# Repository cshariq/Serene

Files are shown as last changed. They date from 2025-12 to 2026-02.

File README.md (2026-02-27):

# SERENE

Can't hear your friend talking on the highway? Do you need to blast your music just to hear it well? Well, you're in luck, because **Serene** is a portable noise-cancelling device that can remove all of that noise!

Just stick it to the roof of your car, and Serene will capture the road noise and output sounds waves that cancel them out, so that you can enjoy a peaceful car ride. 

Serene is a small, portable device that connects directly to your phone and car speaker. It sticks seamlessly to the walls of your car, and using ANC algorithms, it minimizes the external noise that it picks up inside the car.  

---

## Inspiration 

During family road trips, I sat in the backseat as a child, and if I didn't yell, my parents in the front couldn't hear me. This was so annoying, as a long highway drive almost always came with losing my voice. 

With my dad's hearing getting worse, I figured that we needed a way to drown out the road noise. I was desparate for a solution, so taking inspiration from noise-cancelling technology in headphones, I thought: "What if we did the same thing in cars?". 

While a few very luxury cars offer ANC, I wanted to make ANC more accessible to all people, because everyone deserves sereneness!

---

## How to use Serene

1. Click the power ON button at the top of the casing. 
2. Download the Serene app and pair your mobile device through Bluetooth / AUX / USB. 
3. Proceed with the calibration process.
4. Stick the Serene device anywhere in your car.
5. Turn the car on and start your peaceful drive.

---

## 3D Model: [OnShape Link](https://cad.onshape.com/documents/61c8b07b134ed299bc7b3a3e/w/ec2ebddc7aaece6417831267/e/c16017c5fc26cf24515a7a41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)

### PCB:



### Casing:



---

## PCB
### Main PCB


### Button PCB


---

## Wiring Diagram
### Main PCB


### Button PCB



---

## BOM
| Quantity | Part Name | Compoenent | Price(1 Quantity) | Total Price for all quantiy | Link | Status |
|---|---|---|---|---|---|---|
| 1 | WQFN-HR18__RYK_TEX | Power Chip | $2.48 | $2.48 | https://jlcpcb.com/partdetail/TexasInstruments-BQ25620RYKR/C6164243 | In Stock  |
| 2 | CONN_X.FL-R-SMT-180_HIR | Coaxial Connector for bluetooth and UWB antennas | $0.27 | $0.53 | https://jlcpcb.com/partdetail/HRS_Hirose-X_FL_R_SMT_1_80/C434819 | In Stock  |
| 17 | C_0402_1005Metric | Capacitor, 0.1uF | $0.00 | $0.03 | https://jlcpcb.com/partdetail/MurataElectronics-GRM155R71C104KA88D/C71629 | In Stock  |
| 1 | C_0402_1005Metric | Capacitor, 47nF | $0.00 | $0.00 | https://jlcpcb.com/partdetail/MurataElectronics-GRM155R71E473KA88D/C77017 | In Stock  |
| 1 | Spark_SR1120_QFN32 | UWB Chip, used for audio transmission | $16.54 | $16.54 | https://jlcpcb.com/partdetail/SPARKMicrosystems-SR1120AA_4Q32TR/C47090725 | Pre-Order |
| 1 | SOT-23-5 | 1.8V Power Regulator | $0.11 | $0.11 | https://jlcpcb.com/partdetail/DiodesIncorporated-AP2112K_18TRG1/C176944 | In Stock  |
| 2 | Infineon_PG-LLGA-5-2 | Mics | $10.28 | $20.56 | https://www.aliexpress.com/item/1005009306016183.html?gatewayAdapt=4itemAdapt | In Stock  |
| 1 | USB_C_Receptacle_GCT_USB4085 | USB C Port (USB 2.0) | $1.19 | $1.19 | https://jlcpcb.com/partdetail/8061907-USB4085_GFA/C7095263 | In Stock  |
| 1 | Jack_3.5mm_CUI_SJ2-3593D-SMT_Horizontal | Headphone Jack | $11.30 | $11.30 | https://jlcpcb.com/partdetail/CUI-SJ2_3593D_SMTTR/C4991621 | In Stock  |
| 4 | R_0402_1005Metric | Resistor, 100kΩ | $0.01 | $0.04 | https://jlcpcb.com/partdetail/YAGEO-RC0402FR07100KL/C60491 | In Stock  |
| 1 | STM32H743ZIT6 | Microcontroller, STM32H743ZIT6 | $8.19 | $8.19 | https://jlcpcb.com/partdetail/STMicroelectronics-STM32H743ZIT6/C114408 | In Stock  |
| 7 | C_0402_1005Metric | Capacitor, 10uF | $0.01 | $0.07 | https://jlcpcb.com/partdetail/MurataElectronics-GRM155R60J106ME44D/C76991 | In Stock  |
| 1 | C_0402_1005Metric | Capacitor, 4.7µF | $0.01 | $0.01 | https://jlcpcb.com/partdetail/313626-GRM155R61A475MEAAD/C335105 | In Stock  |
| 1 | ADXL382_Ultralib | Vibration Sensor, used for predicting sound | $28.05 | $28.05 | https://jlcpcb.com/partdetail/AnalogDevices-ADXL382_1BCCZRL7/C41718413 | In Stock  |
| 1 | L_0603_1608Metric | Inductor, 180nH | $0.09 | $0.09 | https://jlcpcb.com/partdetail/MurataElectronics-LQW18ANR18G80D/C162650 | In Stock  |
| 1 | Crystal_SMD_3225-4Pin_3.2x2.5mm | Crystal, 32.768 kHz | $0.49 | $0.49 | https://jlcpcb.com/partdetail/AbraconLLC-ABS07_32_768KHZT/C130253 | In Stock  |
| 5 | C_0402_1005Metric | Capacitor, 1uF | $0.01 | $0.05 | https://jlcpcb.com/partdetail/MurataElectronics-GRM155R61A105KE15D/C76999 | In Stock  |
| 6 | C_0402_1005Metric | Capacitor, 10pF | $0.01 | $0.06 | https://jlcpcb.com/partdetail/MurataElectronics-GRM1555C1H100JA01D/C76946 | In Stock  |
| 1 | ADAU1787_Ultralib | DSP(Digital Signal Processor) used for processing sound | $19.07 | $19.07 | https://jlcpcb.com/partdetail/AnalogDevices-ADAU1787BCBZRL7/C3226201 | In Stock  |
| 1 | SOT-223-3_TabPin2 | 3.3V Power Regulator | $0.29 | $0.29 | https://jlcpcb.com/partdetail/DiodesIncorporated-AP7361C_33E13/C500795 | In Stock  |
| 2 | R_0402_1005Metric | Resistor, 5.1k | $0.01 | $0.02 | https://jlcpcb.com/partdetail/YAGEO-RC0402FR075K1L/C105872 | In Stock  |
| 1 | L_0603_1608Metric | Inductor, 1.5uH | $0.10 | $0.10 | https://jlcpcb.com/partdetail/MurataElectronics-DFE252012F_1R5MP2/C909806 | In Stock  |
| 1 | BGM220S_SIL | Bluetooth Chip | $13.84 | $13.84 | https://jlcpcb.com/partdetail/1603489-BGM220SC12WGA2R/C1512693 | Pre-Order |
| 1 | Crystal_SMD_3225-4Pin_3.2x2.5mm | Crystal | $0.08 | $0.08 | https://jlcpcb.com/partdetail/YXC_CrystalOscillators-X322525MQB4SI/C70585 | In Stock  |
| 1 | Balun_Johanson_1.6x0.8mm | Transformer | $8.97 | $8.97 | https://jlcpcb.com/partdetail/YXC_CrystalOscillators-X322525MQB4SI/C70585 | In Stock  |
| 2 | R_0402_1005Metric | Resistor, 2.2kΩ | $0.01 | $0.02 | https://jlcpcb.com/partdetail/YAGEO-RC0402FR072K2L/C114762 | In Stock  |
| 1 | R_0402_1005Metric | Resistor, 170Ω | $0.01 | $0.01 | https://jlcpcb.com/partdetail/YAGEO-RC0402FR07180RL/C138045 | In Stock  |
| 5 | R_0402_1005Metric | Resistor, 10kΩ | $0.01 | $0.05 | https://jlcpcb.com/partdetail/YAGEO-RC0402FR0710KL/C60490 | In Stock  |
| 2 | C_0402_1005Metric | Capacitor, 2.2uF | $0.01 | $0.02 | https://jlcpcb.com/partdetail/MurataElectronics-GRM155R61A225KE95D/C77002 | In Stock  |
| 1 | SOT-23-6 | ESD protection diode, used for headphone jack | $0.13 | $0.13 | https://jlcpcb.com/partdetail/STMicroelectronics-USBLC62SC6/C7519 | In Stock  |
| 2 | CONN_503480-0540_MOL | Molex connector used for linking button PCB with main PCB | $0.83 | $1.66 | https://jlcpcb.com/partdetail/MOLEX-5034800540/C5527934 | In Stock  |
| 3 | LED_SK6805_PLCC4_2.4x2.7mm_P1.3mm | LEDS on the Button PCB | $3.95 | $11.86 | https://www.adafruit.com/product/4492 | In Stock  |
| 1 | SW_Push_1P1T_NO_CK_KMR2 | Button on the Button PCB | $0.61 | $0.61 | https://jlcpcb.com/partdetail/CK-KMR221GLFS/C72443 | In Stock  |
| 1 | Vapcell N40 | Battery | $20.00 | $20.00 | https://www.vapcelltech.com/h-pd-193.html | In Stock  |
| 1 | N/A | Nickel Strips used for connecting the + and - of the battery  | $6.45 | $6.45 | https://www.amazon.ca/Nickel-Plated-Connection-Refined-Welding/dp/B0CPFL5ZWM/ | In Stock  |
| 1 | N/A | Pair of Pogo Pins | $6.06 | $6.06 | https://www.amazon.ca/Connector-Positions-Pogopin-Contact-3PIN/dp/B0BXDFJVVZ?th=1 | In Stock  |
| 1 | N/A | uxcell 45mm x 0.5mm 6 Pin FPC/FFC Flat Ribbon Cable Connector | $9.99 | $9.99 | https://www.amazon.ca/gp/product/B00H8PCW06 | |
| 1 | N/A | N/A | $53.85 | $53.85 | | |
| 1 | N/A | N/A | $7.20 | $7.20 | | |

| Subtotal | Source | Notes |
|---|---|---|
| $228.21 | JLCPCB Parts | 2x (JLCPCB requires 2 of each part) |
| $61.05 | JLCPCB PCB | 0.15mm via and epoxy filled & capped selectedas it is required by the ADAU1787 Chip. Lead free coating also selected for safety and its only a dollar extra. 6 Layer manufacturing is selected because it is cheaper than 2/4 layer manufacturing due to a coupon. Although other options were explored, most DSPs(Digital Singal Processors) which is required for fast processing of audio(required for ANC) are WLCSP chips requiring 0.15mm vias which are epoxy filled & capped. Other solutions are too slow for this application.|
| $22.50 | Amazon | |
| $20.56 | AliExpress | |
| $11.86 | Adafruit | For the LEDs |
| $250.08 | All | Not accounting for 2x JLCPCB Parts |
| $364.18 | All | 2x (JLCPCB required 2 of each part) |

| Grand Total | Price | Notes |
|---|---|---|
| JLCParts Grand Total | $238.13 | 2x (JLCPCB required 2 of each part) |
| JLCPCB Grand Total | $72.25 | JLCPCB Advanced is cheaper due to coupons |
| Amazon Subtotal | $16.28 | 22.5 CAD --> 16.28 USD |
| Adafruit Grand Total | $23.08 | |
| AliExpress Grand Total | $20.70 | 28.07 CAD --> 20.70 USD |
| Vapcell Grand Total | $22.99 | |
| Grand Total | $393.43 | |

### Screenshots of total with shipping and taxes.

Amazon:



JLCPCB Parts:



JLCPCB PCB (6 layer manufacturing for Main PCB, less expensive):



JLCPCB PCB (4 layer manufacturing for Main PCB, more expensive and thus **not used**)



Button PCB:



AliExpress:



Vapcell:



Adafruit:



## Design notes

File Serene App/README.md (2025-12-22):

# serene

A new Flutter project.

## Getting Started

This project is a starting point for a Flutter application.

A few resources to get you started if this is your first Flutter project:

- [Lab: Write your first Flutter app](https://docs.flutter.dev/get-started/codelab)
- [Cookbook: Useful Flutter samples](https://docs.flutter.dev/cookbook)

For help getting started with Flutter development, view the
[online documentation](https://docs.flutter.dev/), which offers tutorials,
samples, guidance on mobile development, and a full API reference.

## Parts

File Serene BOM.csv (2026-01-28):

Quantity | Reference | Footprint Name | Part Name | Compoenent | Manufcaturer Part # | Price(1 Quantity) | Total Price for all quantiy | Source | Link | Status | Digikey Part # | Mouser Part #
1 | U6 | BQ25620RYKR | WQFN-HR18__RYK_TEX | Power Chip | BQ25620RYKR | $2.48 | $2.48 | JLCPCB | https://jlcpcb.com/partdetail/TexasInstruments-BQ25620RYKR/C6164243 | In Stock | 296-BQ25620RYKRCT-ND - Cut Tape (CT) | 595-BQ25620RYKR
2 | J1,J6 | Conn_Coaxial | CONN_X.FL-R-SMT-180_HIR | Coaxial Connector for bluetooth and UWB antennas | X.FL-R-SMT-1(80) | $0.27 | $0.53 | JLCPCB | https://jlcpcb.com/partdetail/HRS_Hirose-X_FL_R_SMT_1_80/C434819 | In Stock | 26-X.FL-R-SMT-1(80)CT-ND - Cut Tape (CT) | 798-X.FL-R-SMT-1(80)
17 | C10,C18,C31,C17,C20,C8,C11,C4,C28,C13,C27,C14,C9,C15,C12,C19,C16 | 0.1uF | C_0402_1005Metric | Capacitor, 0.1uF | GRM155R71C104KA88D | $0.00 | $0.03 | JLCPCB | https://jlcpcb.com/partdetail/MurataElectronics-GRM155R71C104KA88D/C71629 | In Stock | 399-C0603C104K5RACTUCT-ND - Cut Tape (CT) | 963-MBASE105SB7104KF
1 | C37 | 47nF | C_0402_1005Metric | Capacitor, 47nF | GRM155R71E473KA88D | $0.00 | $0.00 | JLCPCB | https://jlcpcb.com/partdetail/MurataElectronics-GRM155R71E473KA88D/C77017 | In Stock | 490-3254-1-ND - Cut Tape (CT) | 81-GRM155R71E473KA88
1 | U9 | ~ | Spark_SR1120_QFN32 | UWB Chip, used for audio transmission | SR1120AA-4Q32-TR | $16.54 | $16.54 | JLCPCB | https://jlcpcb.com/partdetail/SPARKMicrosystems-SR1120AA_4Q32TR/C47090725 | Pre-Order | 3918-SR1120AA-4Q32-TRCT-ND - Cut Tape (CT) | Not avaliable yet, new product
1 | U2 | AP2112K-1.8 | SOT-23-5 | 1.8V Power Regulator | AP2112K-1.8TRG1 | $0.11 | $0.11 | JLCPCB | https://jlcpcb.com/partdetail/DiodesIncorporated-AP2112K_18TRG1/C176944 | In Stock | AP2112K-1.8TRG1DICT-ND - Cut Tape (CT) | 621-AP2112K-1.8TRG1
2 | MK2,MK1 | IM73A135V01 | Infineon_PG-LLGA-5-2 | Mics | IM73A135V01XTSA1 | $10.28 | $20.56 | AliExpress | https://www.aliexpress.com/i/1005008454918413.html | In Stock | 448-IM73A135V01XTSA1CT-ND - Cut Tape (CT) | 726-IM73A135V01XTSA1
1 | J5 | USB_C_Receptacle_USB2.0_14P | USB_C_Receptacle_GCT_USB4085 | USB C Port (USB 2.0) | USB4085-GF-A | $1.19 | $1.19 | JLCPCB | https://jlcpcb.com/partdetail/8061907-USB4085_GFA/C7095263 | In Stock | 2073-USB4085-GF-ACT-ND - Cut Tape (CT) | 640-USB4085-GF-A
1 | J4 | AudioJack3_Switch | Jack_3.5mm_CUI_SJ2-3593D-SMT_Horizontal | Headphone Jack | SJ2-3593D-SMT-TR | $11.30 | $11.30 | JLCPCB | https://jlcpcb.com/partdetail/CUI-SJ2_3593D_SMTTR/C4991621 | In Stock | CP-SJ2-3593D-SMT-CT-ND | 490-SJ2-3593D-SMT-TR
4 | R12,R16,R10,R9 | 100k½ | R_0402_1005Metric | Resistor, 100k½ | RC0402FR-07100KL | $0.01 | $0.04 | JLCPCB | https://jlcpcb.com/partdetail/YAGEO-RC0402FR07100KL/C60491 | In Stock | 311-100KLRCT-ND - Cut Tape (CT) | 603-RC0402FR-07100KL
1 | U3 | STM32H753ZITx | STM32H743ZIT6 | Microcontroller, STM32H743ZIT6 | STM32H743ZIT6 | $8.19 | $8.19 | JLCPCB | https://jlcpcb.com/partdetail/STMicroelectronics-STM32H743ZIT6/C114408 | In Stock | 497-17721-ND | 511-STM32H753ZIT6
7 | C1,C40,C39,C7,C2,C36,C38 | 10uF | C_0402_1005Metric | Capacitor, 10uF | Murata GRM155R60J106ME44D | $0.01 | $0.07 | JLCPCB | https://jlcpcb.com/partdetail/MurataElectronics-GRM155R60J106ME44D/C76991 | In Stock
1 | C35 | 4.7µF | C_0402_1005Metric | Capacitor, 4.7µF | Murata GRM155R61A475MEAAD | $0.01 | $0.01 | JLCPCB | https://jlcpcb.com/partdetail/313626-GRM155R61A475MEAAD/C335105 | In Stock | 490-14306-1-ND - Cut Tape (CT) | 81-GRM155R61A475MEAD
1 | U4 | ADXL382-1BCCZ-RL | ADXL382_Ultralib | Vibration Sensor, used for predicting sound | ADXL382-1BCCZ-RL7 | $28.05 | $28.05 | JLCPCB | https://jlcpcb.com/partdetail/AnalogDevices-ADXL382_1BCCZRL7/C41718413 | In Stock | 505-ADXL382-1BCCZ-RL7CT-ND - Cut Tape (CT) | 584-ADXL382-1BCCZRL7
1 | L1 | 180nH | L_0603_1608Metric | Inductor, 180nH | Murata LQW18ANR18G80D | $0.09 | $0.09 | JLCPCB | https://jlcpcb.com/partdetail/MurataElectronics-LQW18ANR18G80D/C162650 | In Stock | 490-LQW18ANR18G80DCT-ND - Cut Tape (CT) | 81-LQW18ANR18G80D
1 | Y2 | 32.768 kHz | Crystal_SMD_3225-4Pin_3.2x2.5mm | Crystal, 32.768 kHz | ABS07-32.768KHZ-T | $0.49 | $0.49 | JLCPCB | https://jlcpcb.com/partdetail/AbraconLLC-ABS07_32_768KHZT/C130253 | In Stock | 644-STDMUA8-32.768KCT-ND - Cut Tape (CT) | 344-NX3215SA32768K8
5 | C32,C23,C29,C30,C26 | 1uF | C_0402_1005Metric | Capacitor, 1uF | GRM155R61A105KE15D | $0.01 | $0.05 | JLCPCB | https://jlcpcb.com/partdetail/MurataElectronics-GRM155R61A105KE15D/C76999 | In Stock
6 | C33,C25,C34,C3,C6,C24 | 10pF | C_0402_1005Metric | Capacitor, 10pF | GRM1555C1H100JA01D | $0.01 | $0.06 | JLCPCB | https://jlcpcb.com/partdetail/MurataElectronics-GRM1555C1H100JA01D/C76946 | In Stock | 490-5921-1-ND - Cut Tape (CT) | 81-GRM1555C1H100JA1D
1 | U5 | ADAU1787BCBZRL | ADAU1787_Ultralib | DSP(Digital Signal Processor) used for processing sound | ADAU1787BCBZRL | $19.07 | $19.07 | JLCPCB | https://jlcpcb.com/partdetail/AnalogDevices-ADAU1787BCBZRL7/C3226201 | In Stock | 505-ADAU1787BCBZRLCT-ND - Cut Tape (CT) | 584-ADAU1787BCBZRL
1 | U1 | AP7361C-33E | SOT-223-3_TabPin2 | 3.3V Power Regulator | AP7361C-33E-13 | $0.29 | $0.29 | JLCPCB | https://jlcpcb.com/partdetail/DiodesIncorporated-AP7361C_33E13/C500795 | In Stock | AP7361C-33E-13DICT-ND - Cut Tape (CT) | 621-AP7361C-33E-13
2 | R2,R1 | 5.1k | R_0402_1005Metric | Resistor, 5.1k | RC0402FR-075K1L | $0.01 | $0.02 | JLCPCB | https://jlcpcb.com/partdetail/YAGEO-RC0402FR075K1L/C105872 | In Stock | 311-5.10KLRCT-ND - Cut Tape (CT) | 603-RC0402FR-075K1L
1 | L2 | 1.5uH | L_0603_1608Metric | Inductor, 1.5uH | Murata DFE252012F-1R5M=P2 | $0.10 | $0.10 | JLCPCB | https://jlcpcb.com/partdetail/MurataElectronics-DFE252012F_1R5MP2/C909806 | In Stock | 490-13054-1-ND - Cut Tape (CT) | 81-DFE252012F-1R5MP2
1 | U7 | BGM220SC12WGA2R | BGM220S_SIL | Bluetooth Chip | BGM220SC12WGA2R | $13.84 | $13.84 | JLCPCB | https://jlcpcb.com/partdetail/1603489-BGM220SC12WGA2R/C1512693 | Pre-Order | 336-BGM220SC12WGA2RCT-ND - Cut Tape (CT) | 634-BGM220SC12WGA2R
1 | Y1 | Crystal_GND24 | Crystal_SMD_3225-4Pin_3.2x2.5mm | Crystal | X322525MQB4SI | $0.08 | $0.08 | JLCPCB | https://jlcpcb.com/partdetail/YXC_CrystalOscillators-X322525MQB4SI/C70585 | In Stock
1 | T1 | Transformer_1P_1S | Balun_Johanson_1.6x0.8mm | Transformer | Johanson 6750BL14A0100001T | $8.97 | $8.97 | JLCPCB | https://jlcpcb.com/partdetail/YXC_CrystalOscillators-X322525MQB4SI/C70585 | In Stock
2 | R4,R5 | 2.2k½ | R_0402_1005Metric | Resistor, 2.2k½ | RC0402FR-072K2L | $0.01 | $0.02 | JLCPCB | https://jlcpcb.com/partdetail/YAGEO-RC0402FR072K2L/C114762 | In Stock | 311-2.20KLRCT-ND - Cut Tape (CT) | 603-RC0402FR-072K2L
1 | R6 | 170½ | R_0402_1005Metric | Resistor, 170½ | RC0402FR-07170RL | $0.01 | $0.01 | JLCPCB | https://jlcpcb.com/partdetail/YAGEO-RC0402FR07180RL/C138045 | In Stock
5 | R8,R15,R11,R7, R3 | 10k½ | R_0402_1005Metric | Resistor, 10k½ | RC0402FR-0710KL | $0.01 | $0.05 | JLCPCB | https://jlcpcb.com/partdetail/YAGEO-RC0402FR0710KL/C60490 | In Stock | 311-10.0KLRCT-ND - Cut Tape (CT) | 603-RC0402FR-0710KL
2 | C21,C22 | 2.2uF | C_0402_1005Metric | Capacitor, 2.2uF | GRM155R61A225KE95D | $0.01 | $0.02 | JLCPCB | https://jlcpcb.com/partdetail/MurataElectronics-GRM155R61A225KE95D/C77002 | In Stock
1 | U8 | USBLC6-2SC6 | SOT-23-6 | ESD protection diode, used for headphone jack | USBLC6-2SC6 | $0.13 | $0.13 | JLCPCB | https://jlcpcb.com/partdetail/STMicroelectronics-USBLC62SC6/C7519 | In Stock | 497-5235-1-ND - Cut Tape (CT) | 511-USBLC6-2SC6
2 | J2 | Conn_01x06_Socket | CONN_503480-0540_MOL | Molex connector used for linking button PCB with main PCB | 5034800540 | $0.83 | $1.66 | JLCPCB | https://jlcpcb.com/partdetail/MOLEX-5034800540/C5527934 | In Stock | 900-5034800540CT-ND - Cut Tape (CT) | 538-503480-0540
3 | D18,D9,D2,D7,D16,D12,D5,D13,D20,D15,D21,D8,D14,D1,D3,D11,D4,D10,D6,D17,D19 | SK6805 | LED_SK6805_PLCC4_2.4x2.7mm_P1.3mm | LEDS on the Button PCB | SK6805-E-J | $3.95 | $11.86 | Adafruit (cheaper than digikey) | https://www.adafruit.com/product/4492 | In Stock
1 | SW1 | SW_Push | SW_Push_1P1T_NO_CK_KMR2 | Button on the Button PCB | KMR221GLFS | $0.61 | $0.61 | JLCPCB | https://jlcpcb.com/partdetail/CK-KMR221GLFS/C72443 | In Stock
1 | Battery | N/A | Vapcell N40 | Battery | Vapcell N40 | $20.00 | $20.00 | VAPCELL | https://www.vapcelltech.com/h-pd-193.html | In Stock
1 | Nickel Strips | N/A | N/A | Nickel Strips used for connecting the + and - of the battery | N/A | $6.45 | $6.45 | Amazon | https://www.amazon.ca/Nickel-Plated-Connection-Refined-Welding/dp/B0CPFL5ZWM/ | In Stock
1 | Pogo Pins | N/A | N/A | Pair of Pogo Pins | N/A | $6.06 | $6.06 | Amazon | https://www.amazon.ca/Connector-Positions-Pogopin-Contact-3PIN/dp/B0BXDFJVVZ?th=1 | In Stock
1 | FPC/FFC Flat Ribbon Cable | N/A | N/A | uxcell 45mm x 0.5mm 6 Pin FPC/FFC Flat Ribbon Cable Connector | N/A | $9.99 | $9.99 | Amazon | https://www.amazon.ca/gp/product/B00H8PCW06
1 | Main PCB | N/A | N/A | N/A | N/A | $53.85 | $53.85 | JLCPCB PCB
1 | Button PCB | N/A | N/A | N/A | N/A | $7.20 | $7.20 | JLCPCB PCB
 |  |  |  |  |  | Subtotal | Source | Notes
 |  |  |  |  |  | $228.21 | JLCPCB Parts | 2x (JLCPCB required 2 of each part)
 |  |  |  |  |  | $61.05 | JLCPCB PCB | 0.15mm via and expoxy filled & capped selectedas it is required by the ADAU1787 Chip. Lead free coating also selecte, because I don't lead and its only a dollar extra.
 |  |  |  |  |  | $22.50 | Amazon | For the pogo pin + molex ribon cable
 |  |  |  |  |  | $22.50 | Amazon
 |  |  |  |  |  | $20.56 | AliExpress
 |  |  |  |  |  | $11.86 | Adafruit | For the LEDs
 |  |  |  |  |  | $250.08 | All | Not accounting for 2x JLCPCB Parts
 |  |  |  |  |  | $364.18 | All | 2x (JLCPCB required 2 of each part)
 |  |  |  |  |  | JLCParts Grand Total | $238.13 | 2x (JLCPCB required 2 of each part)
 |  |  |  |  |  | JLCPCB Grand Total | $72.25 | JLCPCB Advanced is cheaper due to coupons
 |  |  |  |  |  | Amazon Subtotal | $16.28 | 22.5 CAD --> 16.28 USD
 |  |  |  |  |  | Adafruit Grand Total | $23.08
 |  |  |  |  |  | AliExpress Grand Total | $20.70 | 28.07 CAD --> 20.70 USD
 |  |  |  |  |  | Vapcell Grand Total | $22.99
 |  |  |  |  |  | Grand Total | $393.43

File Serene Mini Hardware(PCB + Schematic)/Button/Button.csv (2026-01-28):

Id | Designator | Footprint | Quantity | Designation | Supplier and ref
1 | J2 | CONN_503480-0540_MOL | 1 | Conn_01x06_Socket
2 | D18,D9,D2,D7,D16,D12,D5,D13,D20,D15,D21,D8,D14,D1,D3,D11,D4,D10,D6,D17,D19 | LED_SK6805_PLCC4_2.4x2.7mm_P1.3mm | 21 | SK6805
3 | SW1 | SW_Push_1P1T_NO_CK_KMR2 | 1 | SW_Push

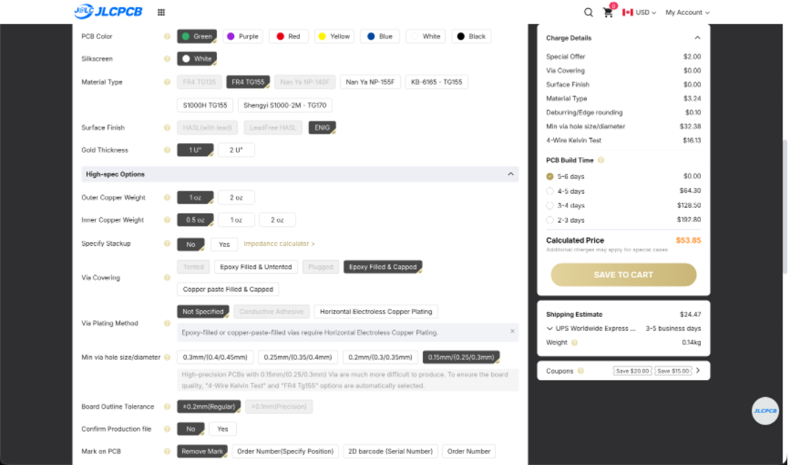
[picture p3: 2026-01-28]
BOM/BOM Checkout Pictures/Picture4.png

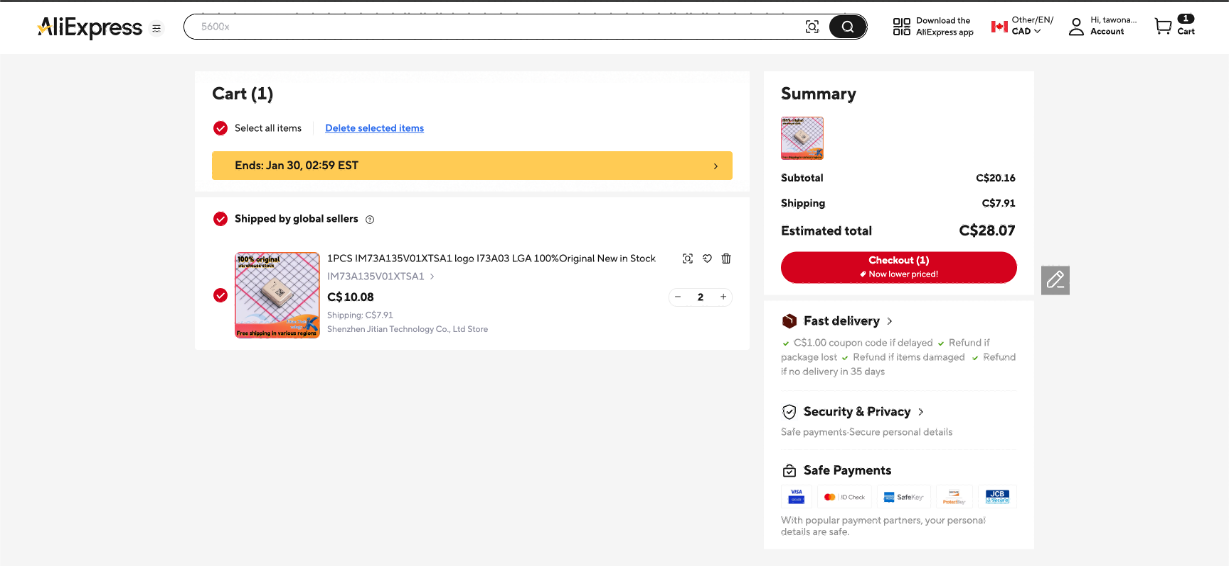
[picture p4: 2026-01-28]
BOM/BOM Checkout Pictures/Picture9.png

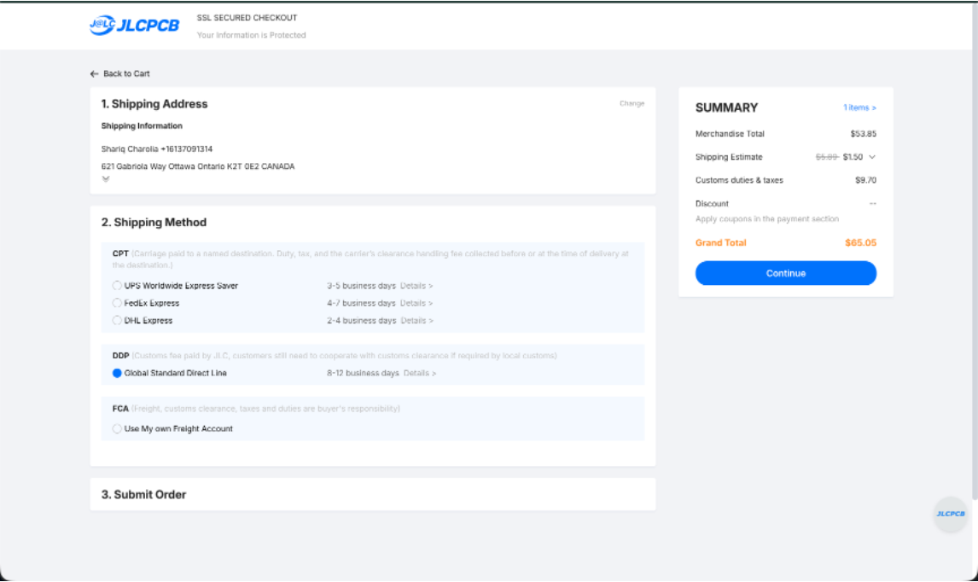
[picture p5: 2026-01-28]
BOM/BOM Checkout Pictures/Picture5.png

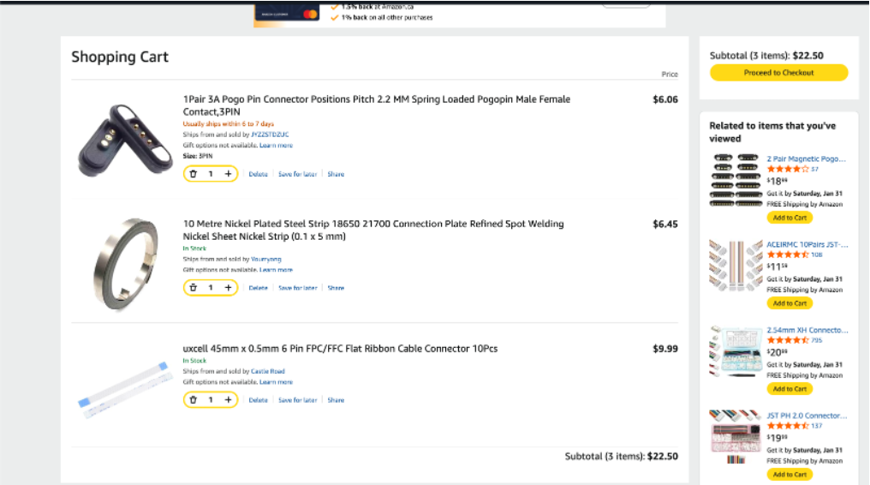
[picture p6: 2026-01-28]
BOM/BOM Checkout Pictures/Picture1.png

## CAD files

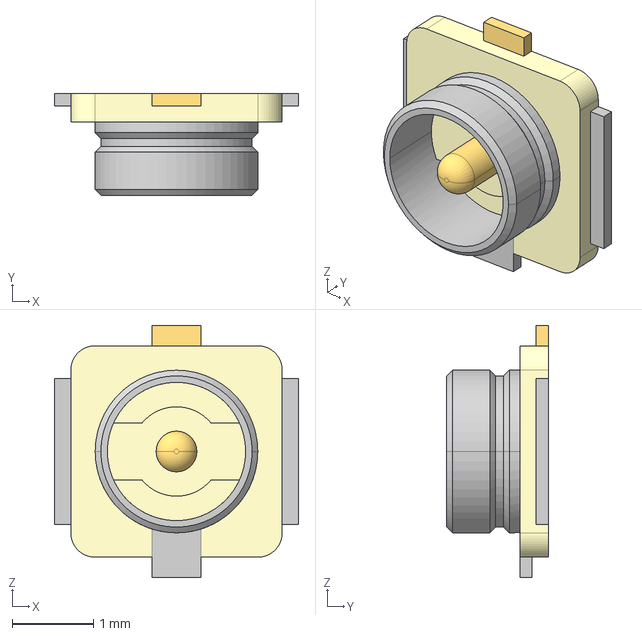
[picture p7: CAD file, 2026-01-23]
Serene Mini Hardware(PCB + Schematic)/Downloaded Models/U.FL-R-SMT-1(01)_CL0331-0472-2-01_3DDrawing_STEP_0001223058S/U.FL-R-SMT-1.stp
3.00 x 1.25 x 3.10 mm

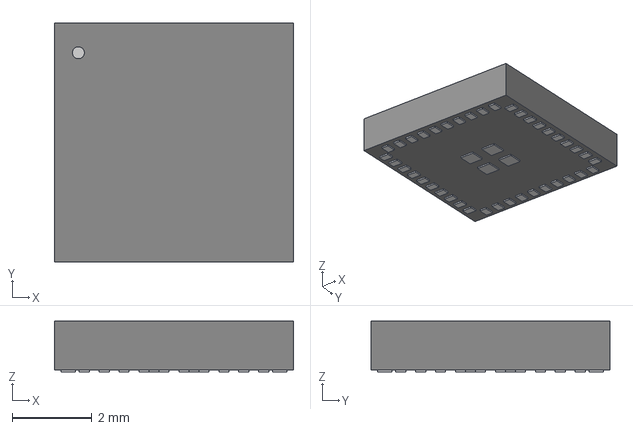
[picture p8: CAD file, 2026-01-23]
Serene Mini Hardware(PCB + Schematic)/Downloaded Models/ul_BGM220SC12WGA2R/BGM220S_SIL.step
5.99 x 5.99 x 1.27 mm

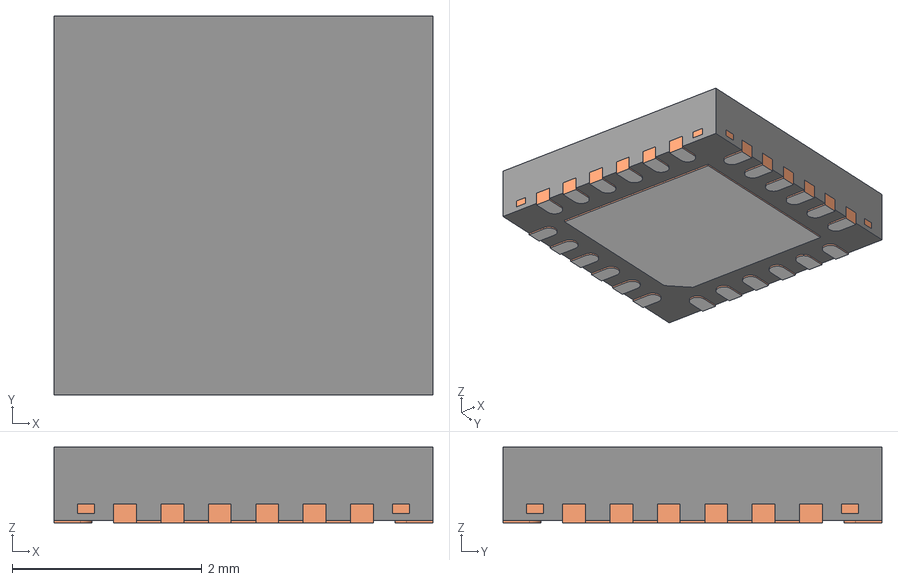
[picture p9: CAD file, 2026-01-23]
Serene Mini Hardware(PCB + Schematic)/Downloaded Models/ul_BQ25616JRTWT/RTW0024H.stp
4.00 x 4.00 x 0.8 mm
BODY-QFN
FRAME-RTW0024H
PIN1-ID

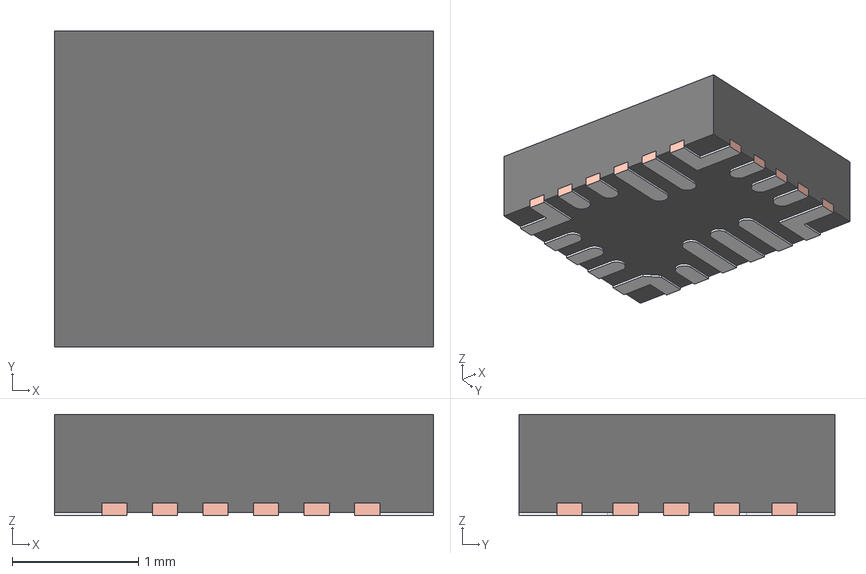
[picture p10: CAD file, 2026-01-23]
Serene Mini Hardware(PCB + Schematic)/Downloaded Models/ul_BQ25620RYKR/RYK0018A.stp
3.00 x 2.50 x 0.8 mm
FRAME
MOLD

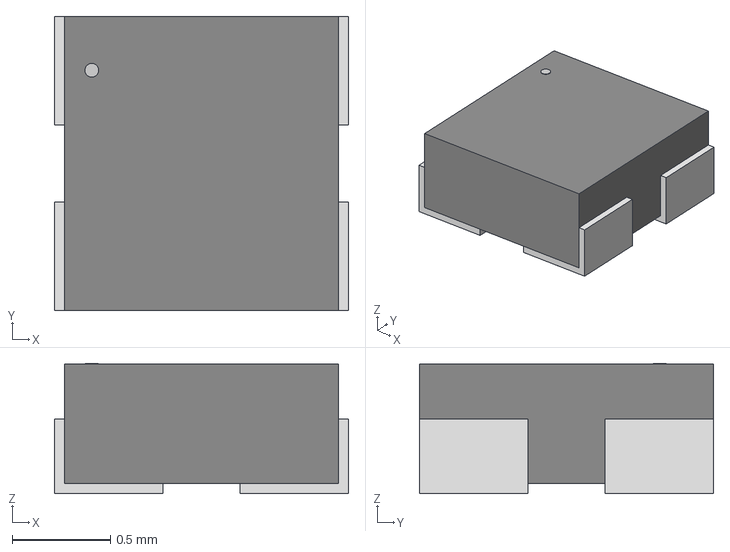
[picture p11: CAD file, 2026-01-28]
Serene Mini Hardware(PCB + Schematic)/Downloaded Models/ul_IPIXEL-SK6805-E-J/IPIXELSK6805-E-J_ADA.step
1.50 x 1.50 x 0.663 mm

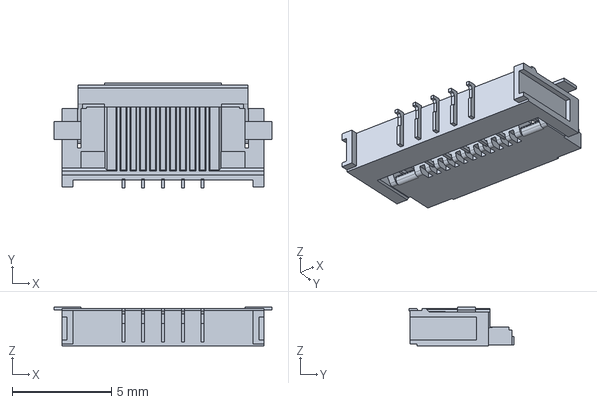
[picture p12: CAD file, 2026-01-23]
Serene Mini Hardware(PCB + Schematic)/Downloaded Models/177503261-659-2005280050/2005280050.stp
11.0 x 5.30 x 1.96 mm

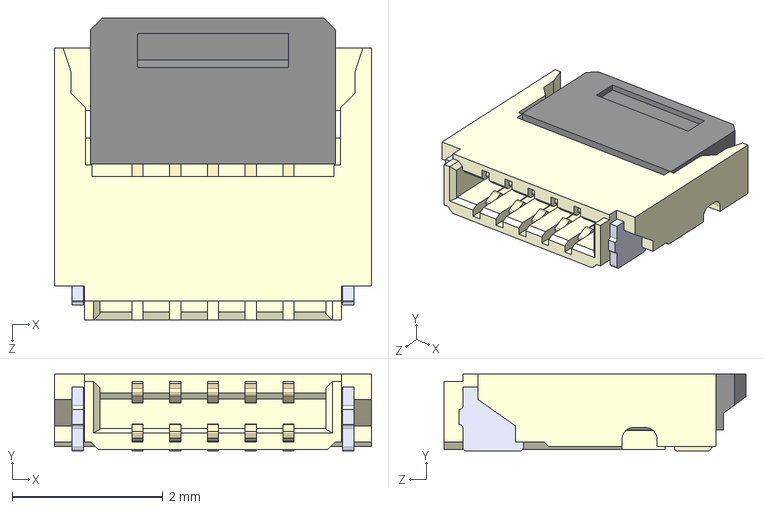
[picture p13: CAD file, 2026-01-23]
Serene Mini Hardware(PCB + Schematic)/Downloaded Models/KiCADv6 3/5034800500.STEP
4.20 x 1.02 x 4.00 mm

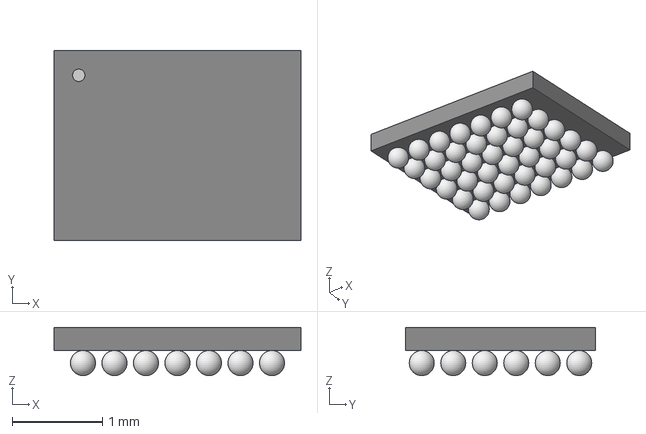
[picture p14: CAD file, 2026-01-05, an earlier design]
Serene Mini Hardware(PCB + Schematic)/Downloaded Models/ul_ADAU1787BCBZRL (1)/CB-42-2_ADI.step
2.74 x 2.11 x 0.536 mm

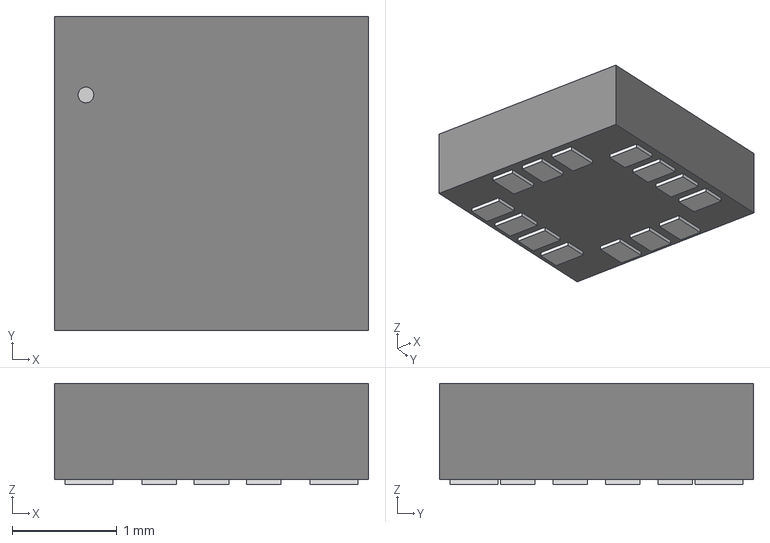
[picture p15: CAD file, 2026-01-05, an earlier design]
Serene Mini Hardware(PCB + Schematic)/Downloaded Models/ul_ADXL382-1BCCZ-RL (1)/CC-14-3_ADI.step
3.00 x 3.00 x 0.968 mm

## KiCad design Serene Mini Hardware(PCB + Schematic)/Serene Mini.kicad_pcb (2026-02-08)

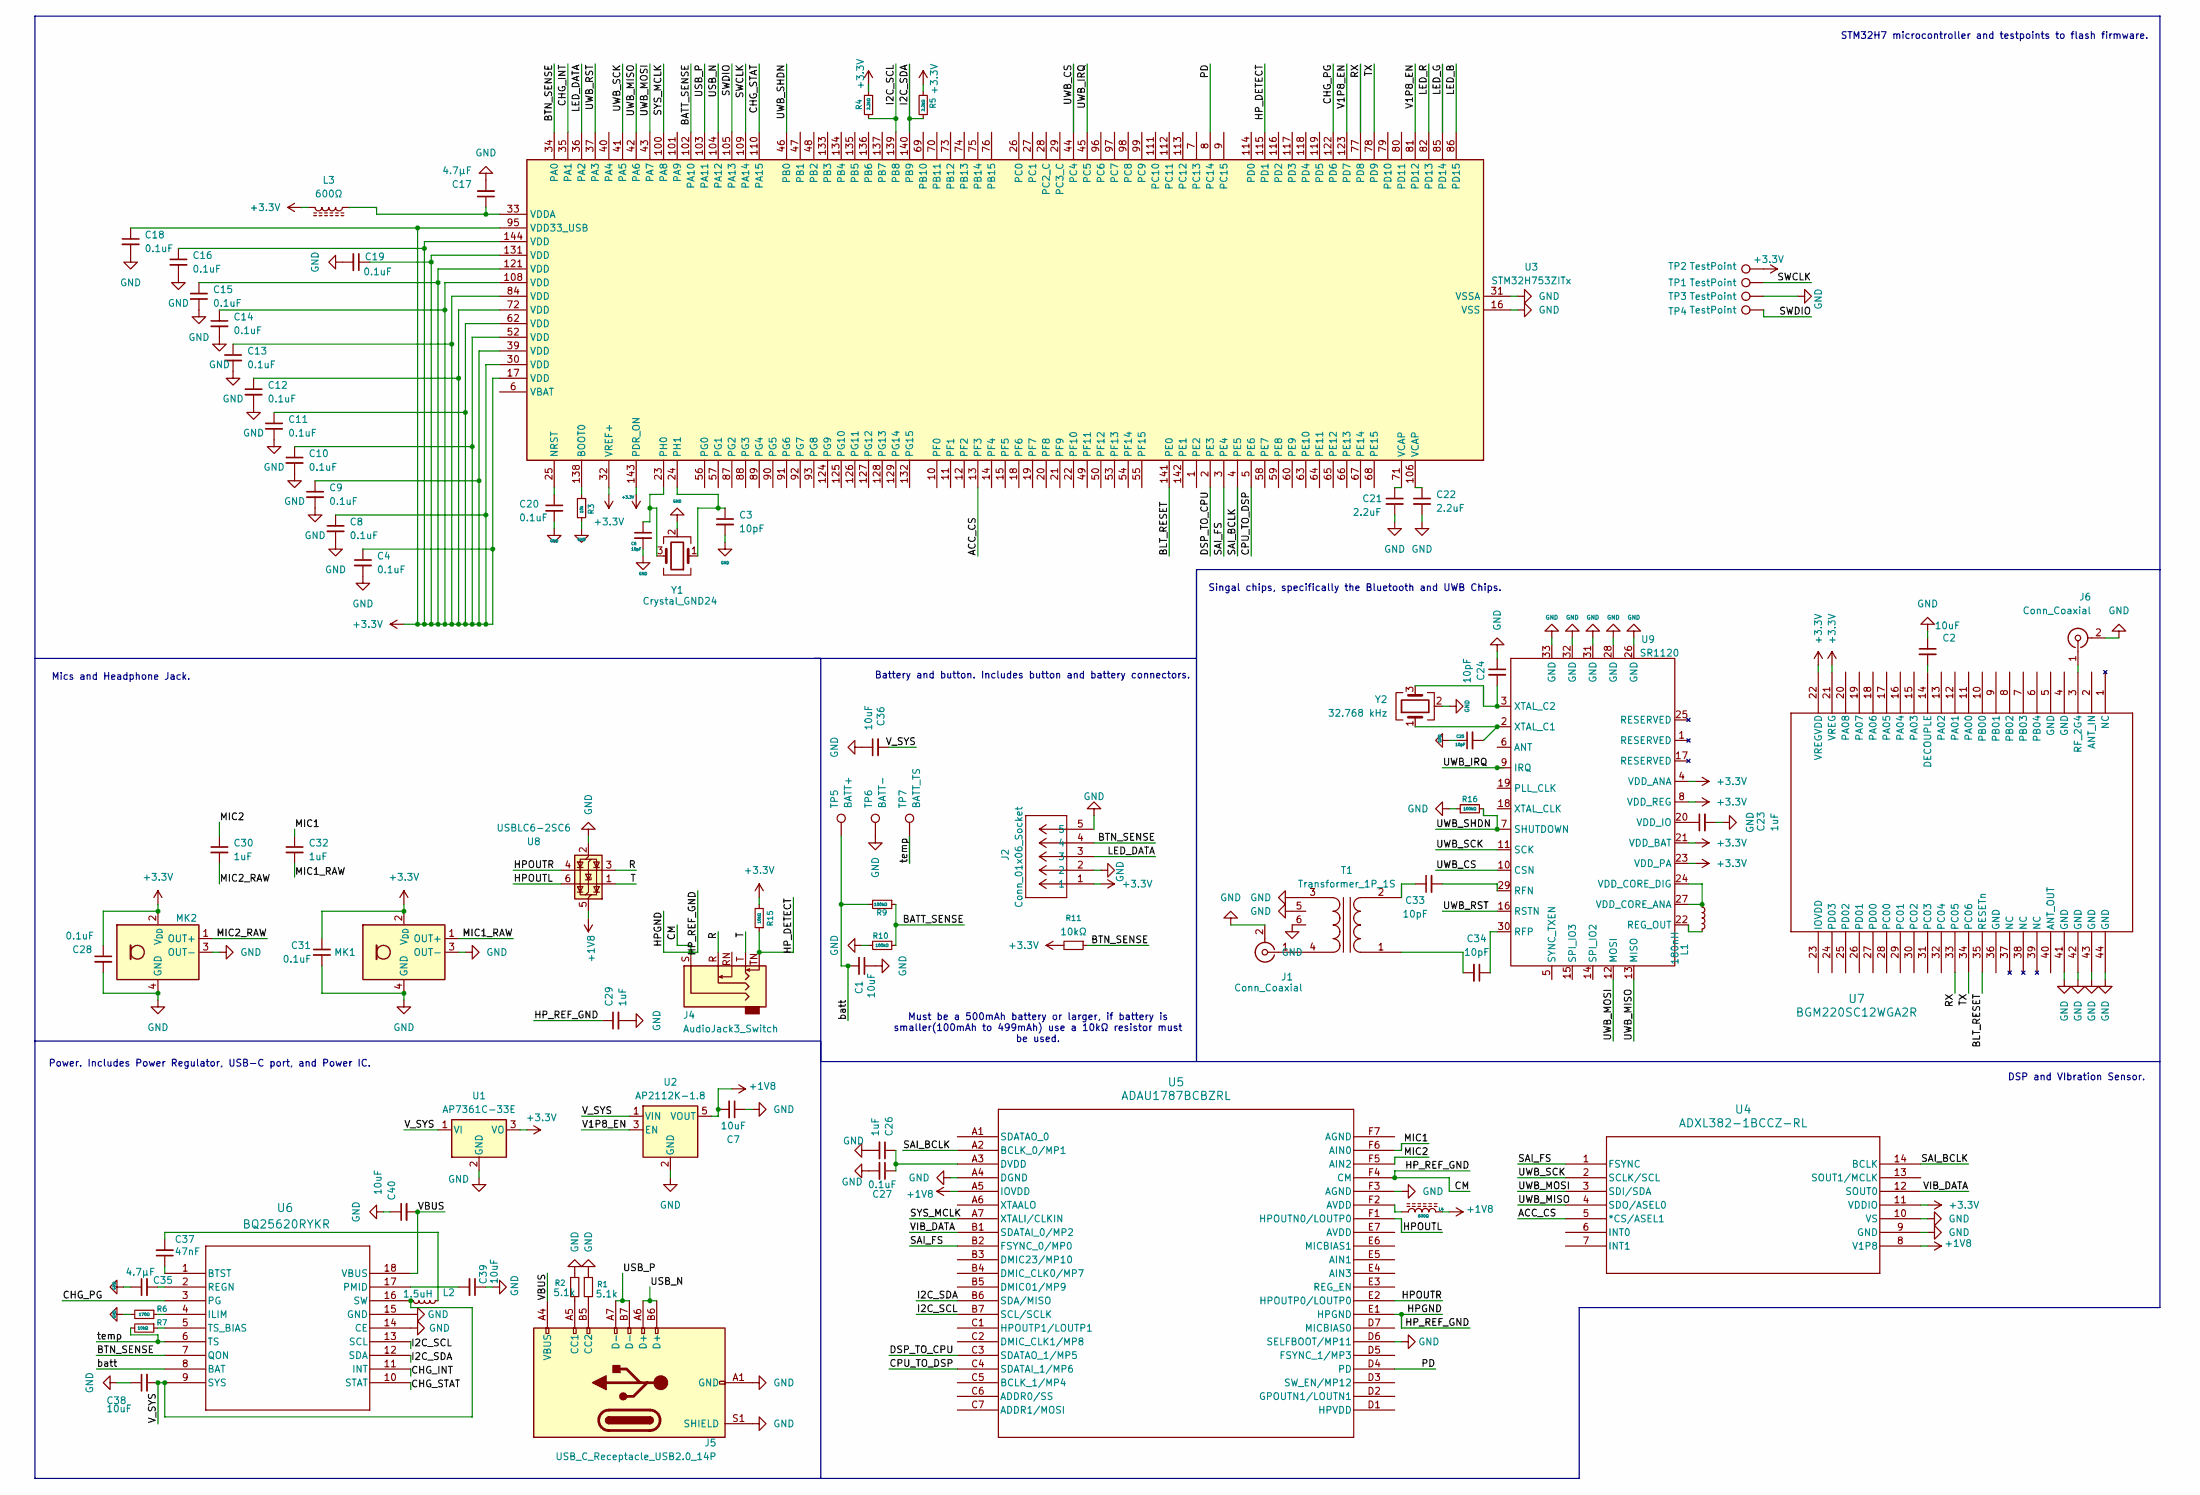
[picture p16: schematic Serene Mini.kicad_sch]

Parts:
C1, C2, C7, C36, C38, C39, C40: 10uF; C_0402_1005Metric
C3, C6, C24, C25, C33, C34: 10pF; C_0402_1005Metric
C4, C8, C9, C10, C11, C12, C13, C14, C15, C16, C18, C19, C20, C27, C28, C31: 0.1uF; C_0402_1005Metric
C17, C35: 4.7µF; C_0402_1005Metric
C21, C22: 2.2uF; C_0402_1005Metric
C23, C26, C29, C30, C32: 1uF; C_0402_1005Metric
C37: 47nF; C_0402_1005Metric
J1, J6: Conn_Coaxial; CONN_X.FL-R-SMT-180_HIR
J2: Conn_01x06_Socket; CONN_503480-0540_MOL
J4: AudioJack3_Switch; Jack_3.5mm_CUI_SJ2-3593D-SMT_Horizontal
J5: USB_C_Receptacle_USB2.0_14P; USB_C_Receptacle_GCT_USB4085
L1: 180nH; L_0603_1608Metric
L2: 1.5uH; L_0603_1608Metric
L3, L4: 600Ω; L_0402_1005Metric
MK1, MK2: IM73A135V01; Infineon_PG-LLGA-5-2
R1, R2: 5.1k; R_0402_1005Metric
R3: 10k; R_0402_1005Metric
R4, R5: 2.2kΩ; R_0402_1005Metric
R6: 170Ω; R_0402_1005Metric
R7, R11, R15: 10kΩ; R_0402_1005Metric
R9, R10, R16: 100kΩ; R_0402_1005Metric
T1: Transformer_1P_1S; Balun_Johanson_1.6x0.8mm
TP1, TP2, TP3, TP4: TestPoint; TestPoint_Pad_1.0x1.0mm
TP5: BATT+; SolderWirePad_1x01_SMD_1x2mm
TP6: BATT-; SolderWirePad_1x01_SMD_1x2mm
TP7: BATT_TS; SolderWirePad_1x01_SMD_1x2mm
U1: AP7361C-33E; SOT-223-3_TabPin2
U2: AP2112K-1.8; SOT-23-5
U3: STM32H753ZITx; LQFP-144_20x20mm_P0.5mm
U4: ADXL382-1BCCZ-RL; ADXL382_Ultralib
U5: ADAU1787BCBZRL; ADAU1787_Ultralib
U6: BQ25620RYKR; WQFN-HR18__RYK_TEX
U7: BGM220SC12WGA2R; BGM220S_SIL
U8: USBLC6-2SC6; SOT-23-6
U9: SR1120; Spark_SR1120_QFN32
Y1: Crystal_GND24; Crystal_SMD_3225-4Pin_3.2x2.5mm
Y2: 32.768 kHz; Crystal_SMD_3225-4Pin_3.2x2.5mm

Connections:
+1V8: C7.2, L4.2, U2.5 (VOUT), U4.8 (V1P8), U5.A5 (IOVDD), U8.5 (VBUS)
+3.3V: C4.1, C8.1, C9.1, C10.1, C11.1, C12.1, C13.1, C14.1, C15.1, C16.1, C18.1, C19.1, C28.1, C31.1, J2.1, L3.2, MK1.2 (V_{DD}), MK2.2 (V_{DD}), R4.2, R5.2, R11.2, R15.2, TP1.1, U1.3 (VO), U3.17 (VDD), U3.30 (VDD), U3.32 (VREF+), U3.39 (VDD), U3.52 (VDD), U3.62 (VDD), U3.72 (VDD), U3.84 (VDD), U3.95 (VDD33_USB), U3.108 (VDD), U3.121 (VDD), U3.131 (VDD), U3.143 (PDR_ON), U3.144 (VDD), U4.11 (VDDIO), U7.21 (VREG), U7.22 (VREGVDD), U9.4 (VDD_ANA), U9.8 (VDD_REG), U9.21 (VDD_BAT), U9.23 (VDD_PA)
/ACC_CS: U3.13 (PF3), U4.5 (*CS/ASEL1)
/BATT_SENSE: R9.1, R10.1, U3.102 (PA10)
/BLT_RESET: U3.141 (PE0), U7.35 (RESETn)
/BTN_SENSE: J2.4, R11.1, U3.34 (PA0), U6.7 (QON)
/CHG_INT: U3.35 (PA1), U6.11 (INT)
/CHG_PG: U3.122 (PD6), U6.3 (PG)
/CHG_STAT: U3.110 (PA15), U6.10 (STAT)
/CM: C29.1, J4.S, U5.E1 (HPGND), U5.F4 (CM)
/CPU_TO_DSP: U3.5 (PE6), U5.C4 (SDATAI_1/MP6)
/DSP_TO_CPU: U3.2 (PE3), U5.C3 (SDATAO_1/MP5)
/HPOUTL: U5.F1 (HPOUTN0/LOUTP0), U8.6 (I/O1)
/HPOUTR: U5.E2 (HPOUTP0/LOUTP0), U8.4 (I/O2)
/HP_DETECT: J4.TN, R15.1, U3.115 (PD1)
/I2C_SCL: R4.1, U3.139 (PB8), U5.B7 (SCL/SCLK), U6.13 (SCL)
/I2C_SDA: R5.1, U3.140 (PB9), U5.B6 (SDA/MISO), U6.12 (SDA)
/LED_B: U3.86 (PD15)
/LED_DATA: J2.3, U3.36 (PA2)
/LED_G: U3.85 (PD14)
/LED_R: U3.82 (PD13)
/MIC1: C32.1, U5.F6 (AIN0)
/MIC1_RAW: C32.2, MK1.1 (OUT+)
/MIC2: C30.1, U5.F5 (AIN2)
/MIC2_RAW: C30.2, MK2.1 (OUT+)
/PD: U3.8 (PC14), U5.D4 (PD)
/R: J4.R, U8.3 (I/O2)
/RX: U3.77 (PD8), U7.33 (PC05)
/SAI_BCLK: U3.4 (PE5), U4.14 (BCLK), U5.A2 (BCLK_0/MP1)
/SAI_FS: U3.3 (PE4), U4.1 (FSYNC), U5.B2 (FSYNC_0/MP0)
/SWCLK: TP2.1, U3.109 (PA14)
/SWDIO: TP4.1, U3.105 (PA13)
/SYS_MCLK: U3.100 (PA8), U5.A7 (XTALI/CLKIN)
/T: J4.T, U8.1 (I/O1)
/TX: U3.78 (PD9), U7.34 (PC06)
/USB_N: J5.A6 (D+), J5.B6 (D+), U3.104 (PA12)
/USB_P: J5.A7 (D-), J5.B7 (D-), U3.103 (PA11)
/UWB_CS: U3.44 (PC4), U9.10 (CSN)
/UWB_IRQ: U3.45 (PC5), U9.9 (IRQ)
/UWB_MISO: U3.42 (PA6), U4.4 (SDO/ASEL0), U9.13 (MISO)
/UWB_MOSI: U3.43 (PA7), U4.3 (SDI/SDA), U9.12 (MOSI)
/UWB_RST: U3.37 (PA3), U9.16 (RSTN)
/UWB_SCK: U3.41 (PA5), U4.2 (SCLK/SCL), U9.11 (SCK)
/UWB_SHDN: R16.2, U3.46 (PB0), U9.7 (SHUTDOWN)
/V1P8_EN: U2.3 (EN), U3.81 (PD12), U3.123 (PD7)
/VBUS: C40.2, J5.A4 (VBUS), J5.A9 (VBUS), J5.B4 (VBUS), J5.B9 (VBUS), U6.18 (VBUS)
/VIB_DATA: U4.12 (SOUT0), U5.B1 (SDATAI_0/MP2)
/V_SYS: C36.2, C38.2, L2.2, U1.1 (VI), U2.1 (VIN), U6.9 (SYS), U6.16 (SW)
/batt: C1.2, R9.2, TP5.1, U6.8 (BAT)
/temp: R7.2, TP7.1, U6.6 (TS)
GND: C1.1, C2.1, C3.2, C4.2, C6.2, C7.1, C8.2, C9.2, C10.2, C11.2, C12.2, C13.2, C14.2, C15.2, C16.2, C17.2, C18.2, C19.2, C20.2, C21.2, C22.2, C23.2, C24.1, C25.1, C26.2, C27.2, C28.2, C29.2, C31.2, C35.1, C36.1, C38.1, C39.1, C40.1, J1.2 (Ext), J2.2, J2.5, J5.A1 (GND), J5.A12 (GND), J5.B1 (GND), J5.B12 (GND), J5.S1 (SHIELD), J6.2 (Ext), MK1.3 (OUT-), MK1.4 (GND), MK1.5 (GND), MK2.3 (OUT-), MK2.4 (GND), MK2.5 (GND), R1.1, R2.1, R3.2, R6.2, R10.2, R16.1, T1.3 (SA), T1.5 (GND), T1.6 (GND), TP3.1, TP6.1, U1.2 (GND), U2.2 (GND), U3.16 (VSS), U3.31 (VSSA), U3.38 (VSS), U3.51 (VSS), U3.61 (VSS), U3.83 (VSS), U3.94 (VSS), U3.107 (VSS), U3.120 (VSS), U3.130 (VSS), U4.9 (GND), U4.10 (VS), U5.A4 (DGND), U5.D6 (SELFBOOT/MP11), U5.F3 (AGND), U6.1 (BTST), U6.5 (TS_BIAS), U6.10 (STAT), U6.14 (CE), U6.15 (GND), U7.41 (GND), U7.42 (GND), U7.43 (GND), U7.44 (GND), U8.2 (GND), U9.26 (GND), U9.28 (GND), U9.31 (GND), U9.32 (GND), U9.33 (GND), Y1.2 (G), Y1.4 (G), Y2.2 (G), Y2.4 (G)
unnamed: C21.1, U3.71 (VCAP)
unnamed: C22.1, U3.106 (VCAP)
unnamed: C37.2, L2.1
unnamed: J1.1 (In), T1.4 (SB)
unnamed: J5.A5 (CC1), R2.2
unnamed: J5.B5 (CC2), R1.2
unnamed: J6.1 (In), U7.3 (RF_2G4)
unnamed: L4.1, U5.F2 (AVDD)
unnamed: C34.2, T1.1 (AA)
unnamed: C33.1, T1.2 (AB)
unnamed: R3.1, U3.138 (BOOT0)
unnamed: C20.1, U3.25 (NRST)
unnamed: C6.1, U3.23 (PH0), Y1.3
unnamed: C3.1, U3.24 (PH1), Y1.1
unnamed: C17.1, L3.1, U3.33 (VDDA)
unnamed: C26.1, C27.1, U5.A3 (DVDD)
unnamed: C37.1, U6.1 (BTST)
unnamed: R6.1, U6.4 (ILIM)
unnamed: C39.2, U6.17 (PMID)
unnamed: C35.2, U6.2 (REGN)
unnamed: R7.1, U6.5 (TS_BIAS)
unnamed: C2.2, U7.14 (DECOUPLE)
unnamed: L1.2, U9.22 (REG_OUT)
unnamed: C33.2, U9.29 (RFN)
unnamed: C34.1, U9.30 (RFP)
unnamed: L1.1, U9.24 (VDD_CORE_DIG), U9.27 (VDD_CORE_ANA)
unnamed: C23.1, U9.20 (VDD_IO)
unnamed: C25.2, U9.2 (XTAL_C1), Y2.1
unnamed: C24.2, U9.3 (XTAL_C2), Y2.3

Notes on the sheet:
Must be a 500mAh battery or larger, if battery is smaller(100mAh to 499mAh) use a 10kΩ resistor must be used.
STM32H7 microcontroller and testpoints to flash firmware.
Battery and button. Includes button and battery connectors.
DSP and VIbration Sensor.
Power. Includes Power Regulator, USB-C port, and Power IC.
Singal chips, specifically the Bluetooth and UWB Chips.
Mics and Headphone Jack.

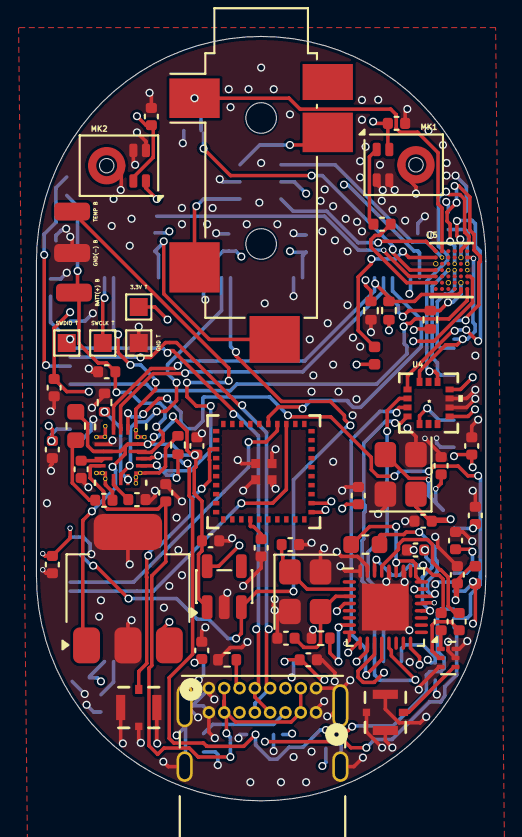
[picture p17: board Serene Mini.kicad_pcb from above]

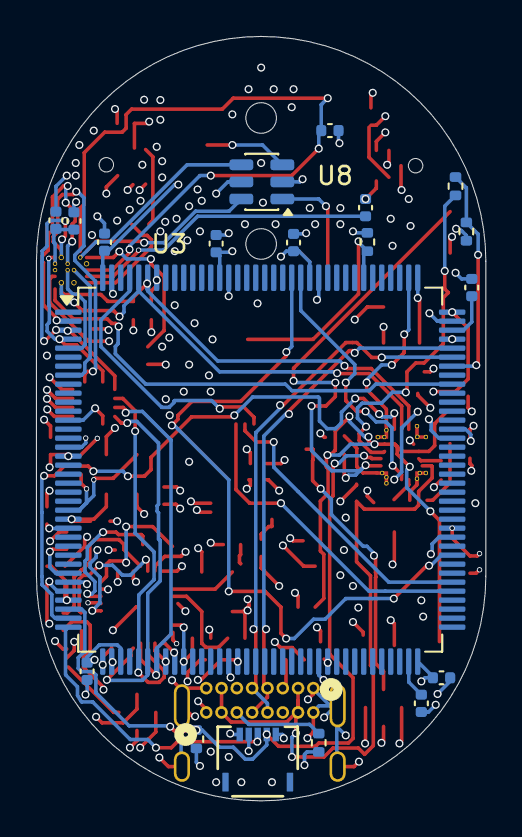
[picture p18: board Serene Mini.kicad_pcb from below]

Board: 6 copper layers, 25.0 x 42.5 mm, 81 parts (19 on the bottom side), 77 nets.

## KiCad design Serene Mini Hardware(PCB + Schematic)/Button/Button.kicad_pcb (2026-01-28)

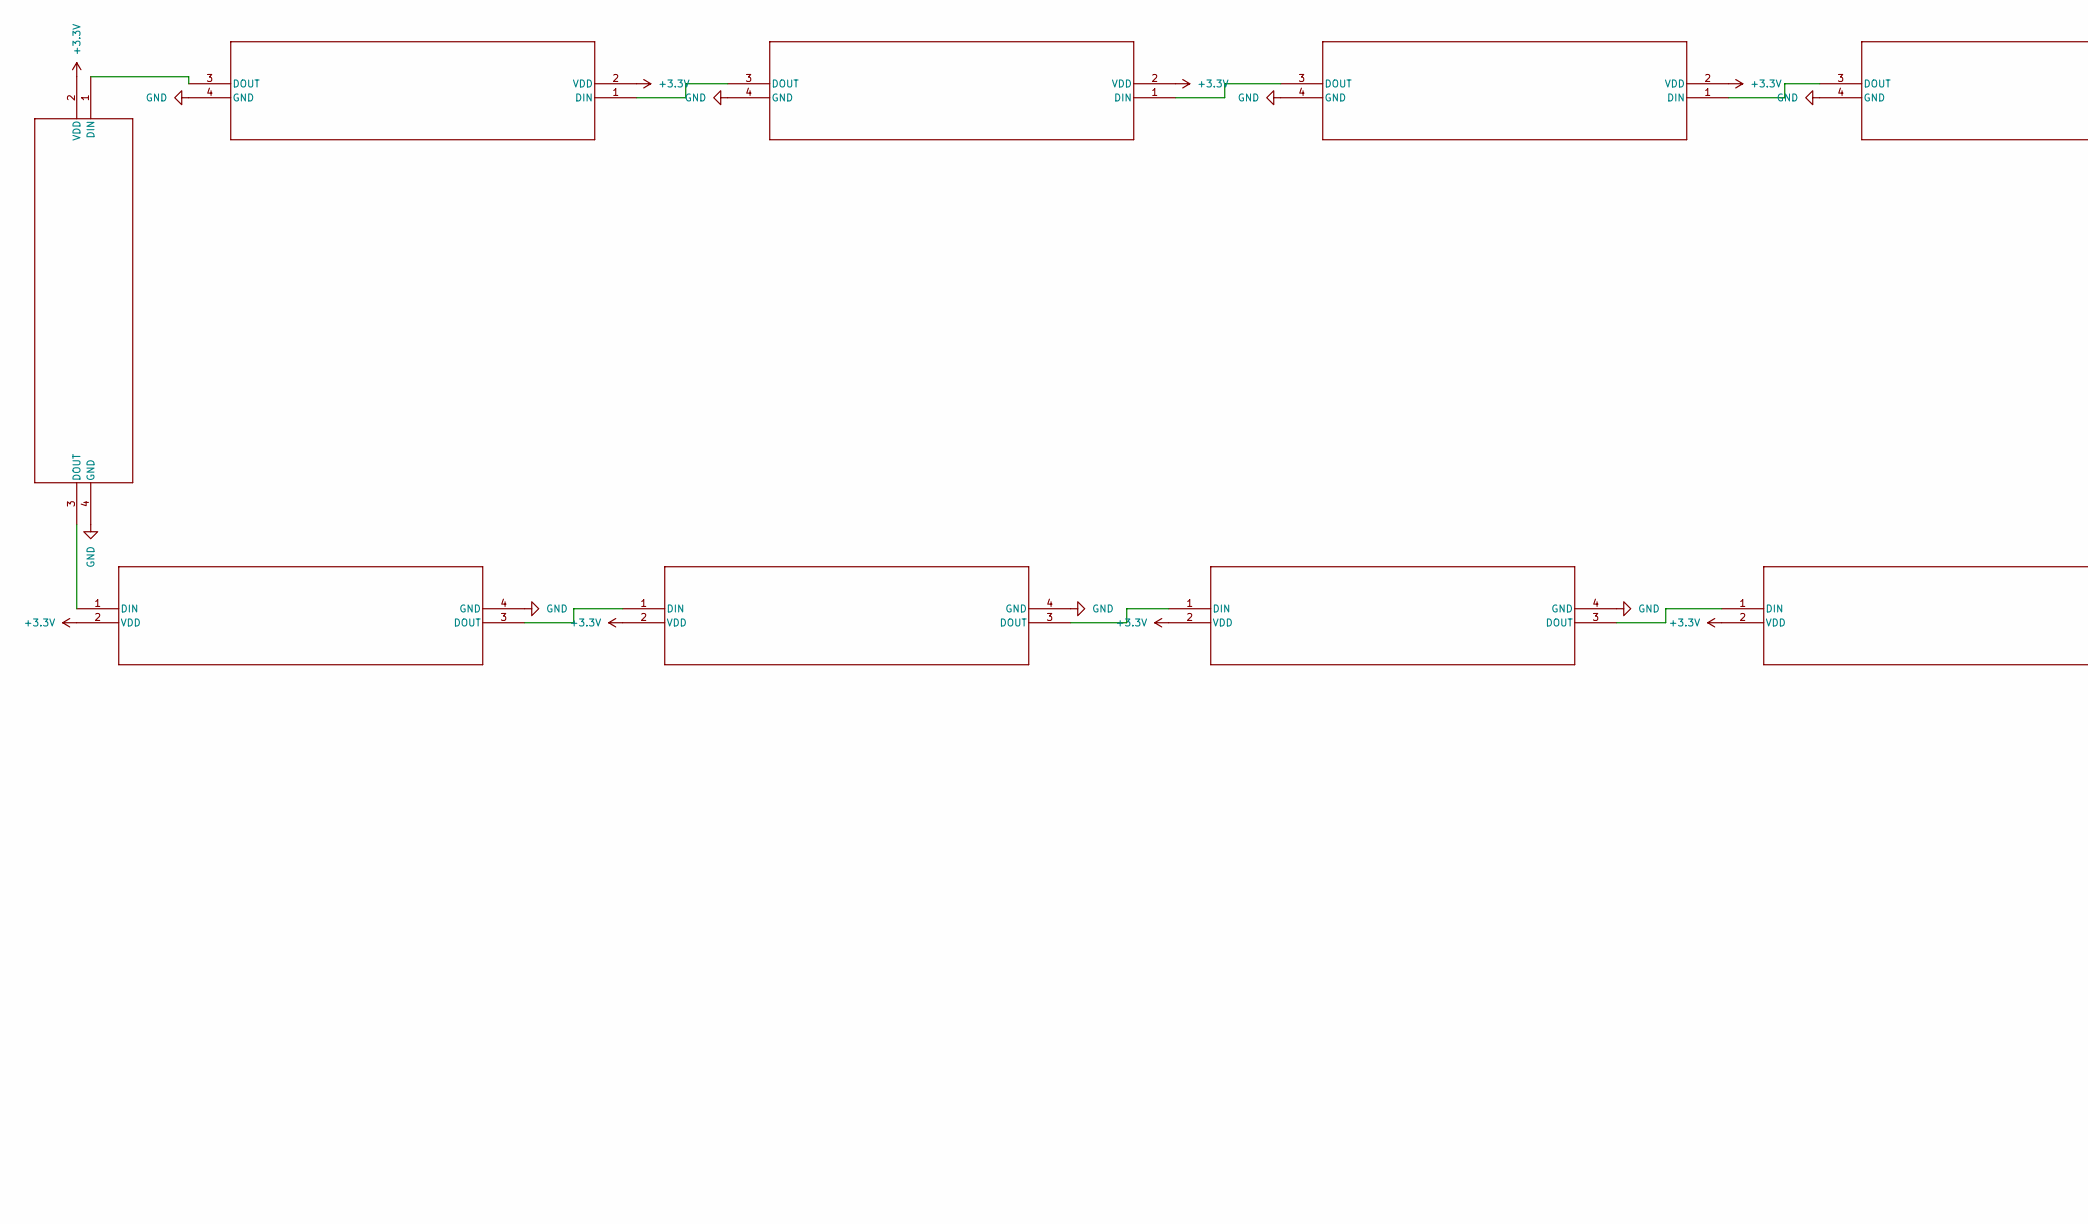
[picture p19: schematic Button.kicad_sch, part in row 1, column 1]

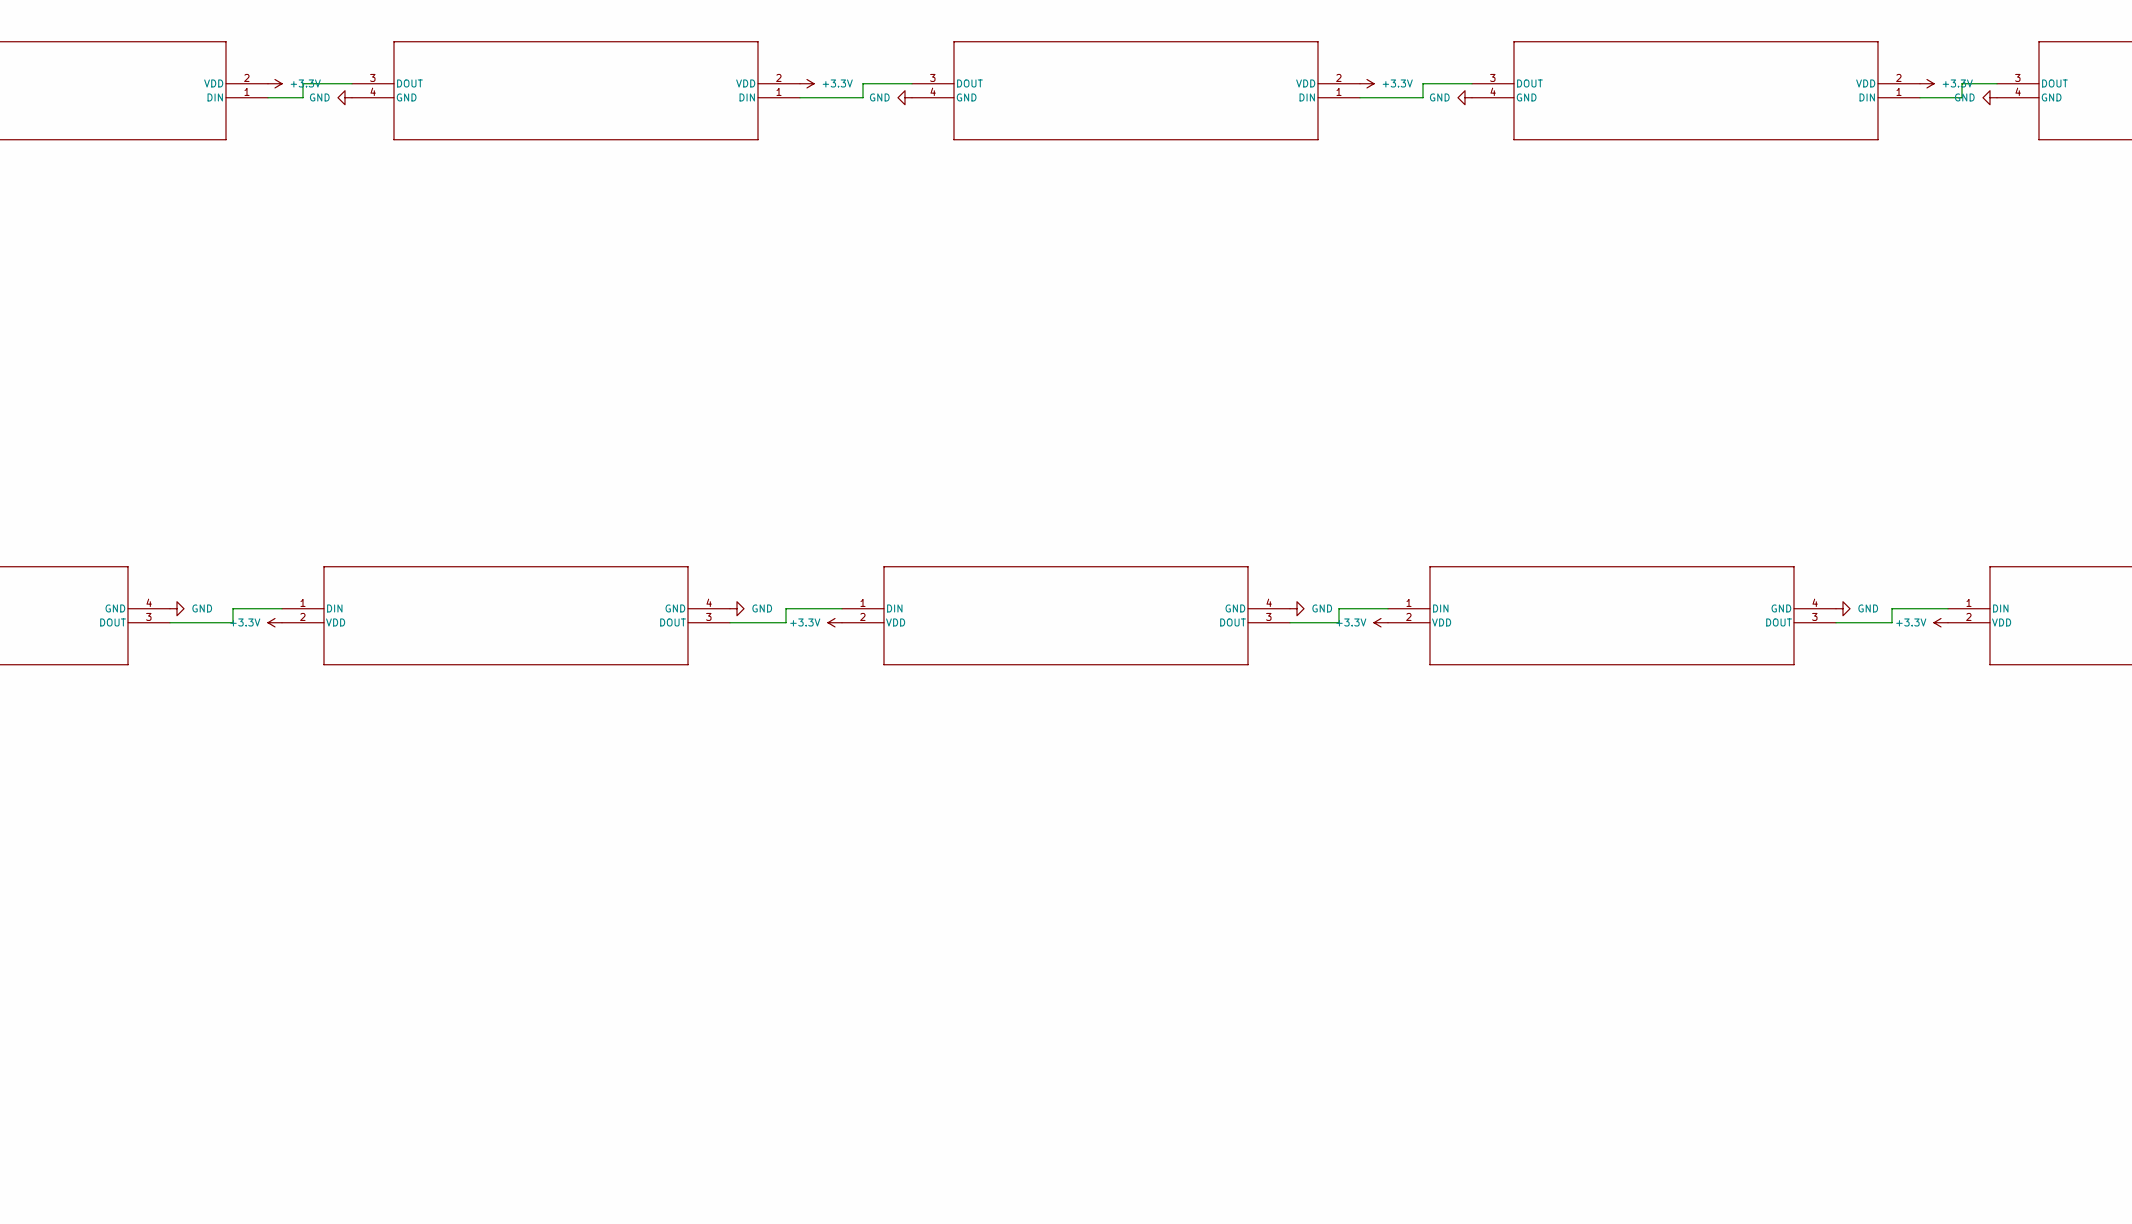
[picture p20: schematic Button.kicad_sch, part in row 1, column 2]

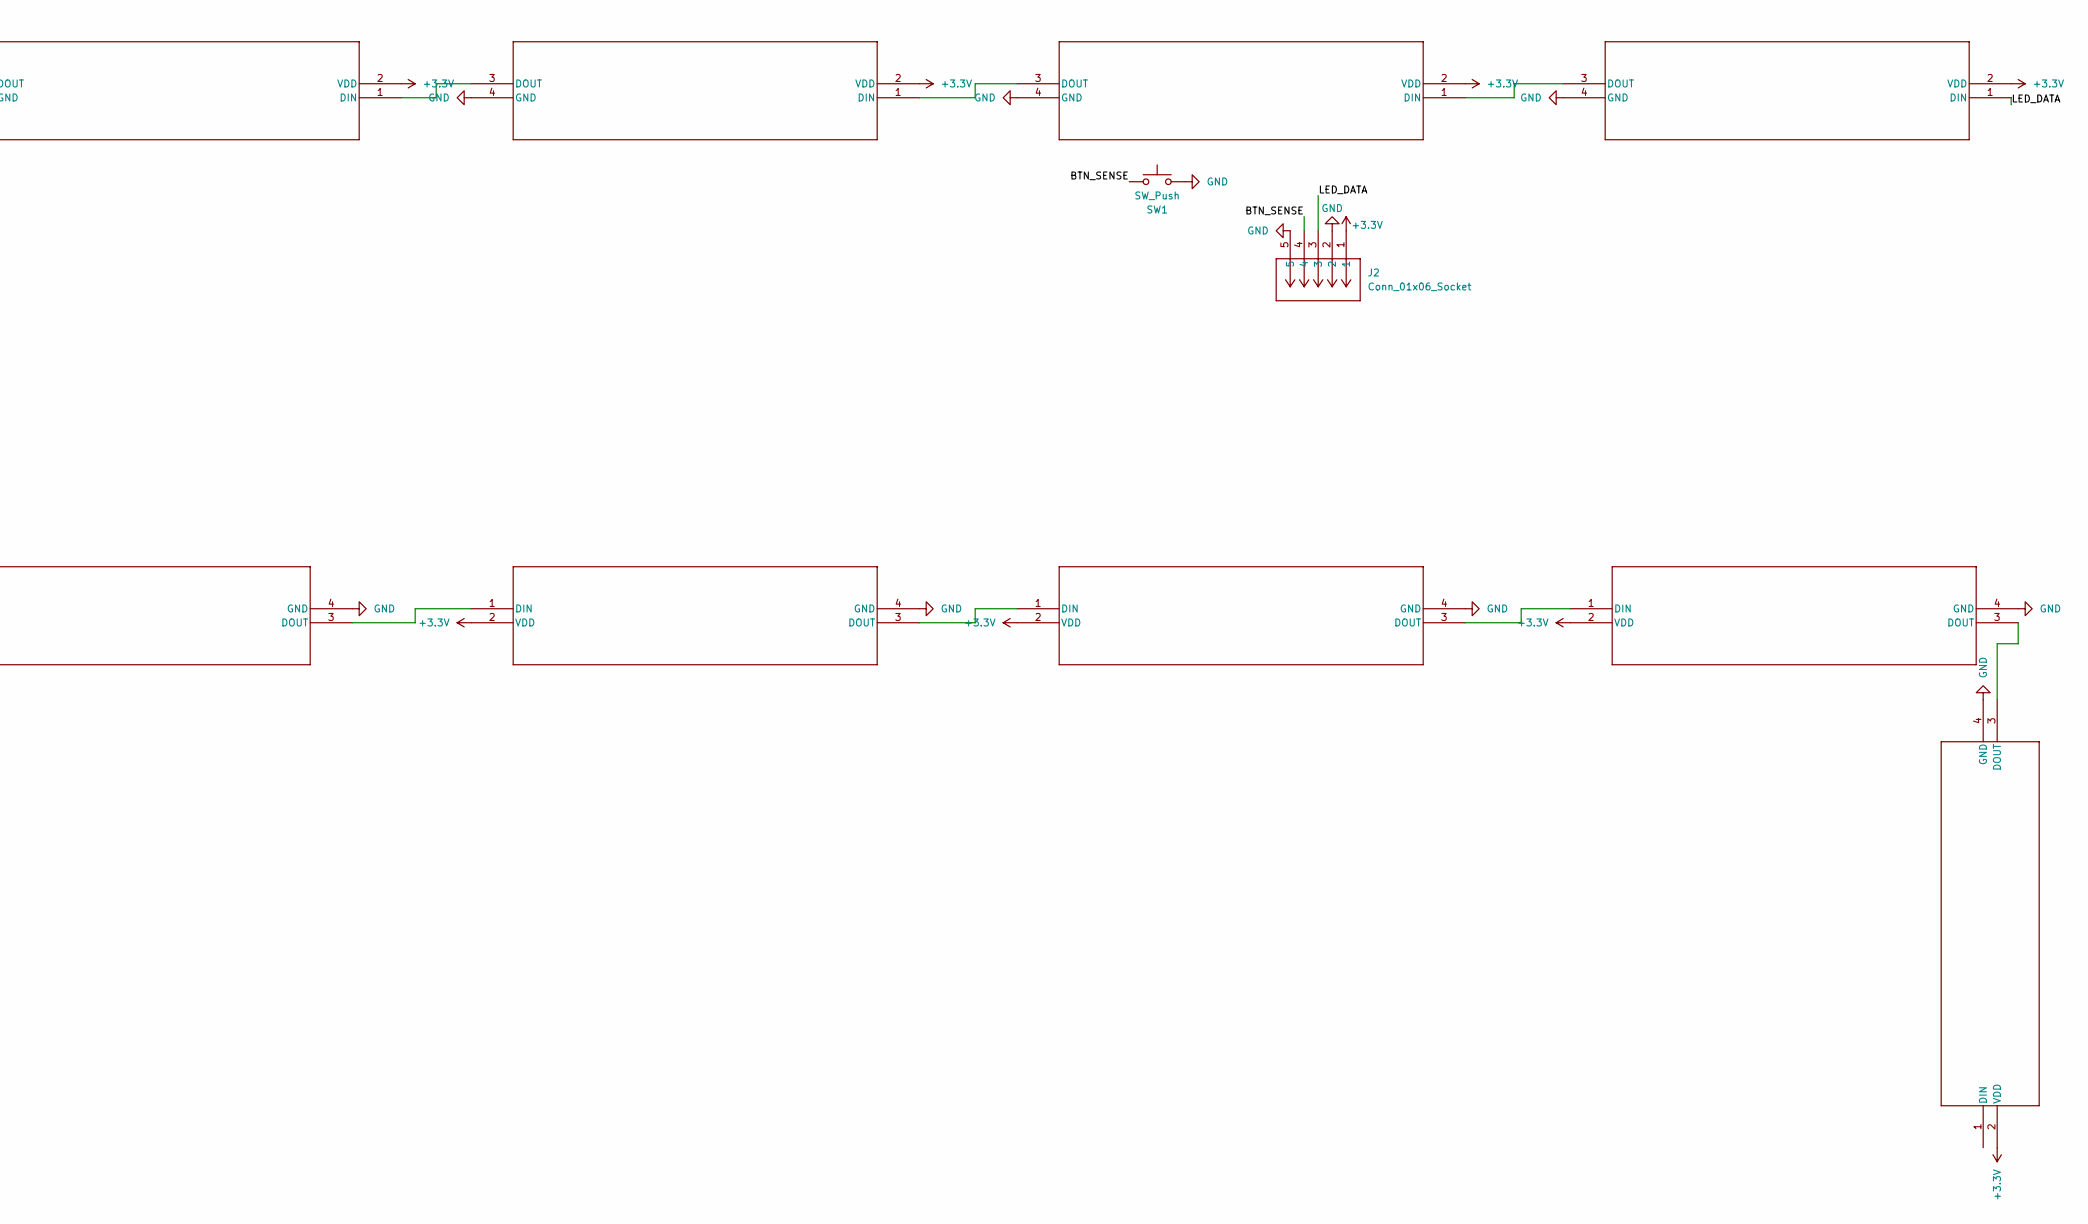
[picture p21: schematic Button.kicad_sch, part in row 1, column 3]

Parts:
D1, D2, D3, D4, D5, D6, D7, D8, D9, D10, D11, D12, D13, D14, D15, D16, D17, D18, D19, D20, D21, D22, D23, D24: SK6805; IPIXEL SK6805-E-J_ADA
J2: Conn_01x06_Socket; CONN_503480-0540_MOL
SW1: SW_Push; SW_Push_1P1T_NO_CK_KMR2

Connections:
+3.3V: D1.2 (VDD), D2.2 (VDD), D3.2 (VDD), D4.2 (VDD), D5.2 (VDD), D6.2 (VDD), D7.2 (VDD), D8.2 (VDD), D9.2 (VDD), D10.2 (VDD), D11.2 (VDD), D12.2 (VDD), D13.2 (VDD), D14.2 (VDD), D15.2 (VDD), D16.2 (VDD), D17.2 (VDD), D18.2 (VDD), D19.2 (VDD), D20.2 (VDD), D21.2 (VDD), D22.2 (VDD), D23.2 (VDD), D24.2 (VDD), J2.1
/BTN_SENSE: J2.4, SW1.1
/LED_DATA: D1.1 (DIN), J2.3
GND: D1.4 (GND), D2.4 (GND), D3.4 (GND), D4.4 (GND), D5.4 (GND), D6.4 (GND), D7.4 (GND), D8.4 (GND), D9.4 (GND), D10.4 (GND), D11.4 (GND), D12.4 (GND), D13.4 (GND), D14.4 (GND), D15.4 (GND), D16.4 (GND), D17.4 (GND), D18.4 (GND), D19.4 (GND), D20.4 (GND), D21.4 (GND), D22.4 (GND), D23.4 (GND), D24.4 (GND), J2.2, J2.5, SW1.2
unnamed: D1.3 (DOUT), D2.1 (DIN)
unnamed: D2.3 (DOUT), D3.1 (DIN)
unnamed: D3.3 (DOUT), D4.1 (DIN)
unnamed: D4.3 (DOUT), D5.1 (DIN)
unnamed: D5.3 (DOUT), D6.1 (DIN)
unnamed: D6.3 (DOUT), D7.1 (DIN)
unnamed: D7.3 (DOUT), D8.1 (DIN)
unnamed: D8.3 (DOUT), D9.1 (DIN)
unnamed: D9.3 (DOUT), D10.1 (DIN)
unnamed: D10.3 (DOUT), D11.1 (DIN)
unnamed: D11.3 (DOUT), D12.1 (DIN)
unnamed: D12.3 (DOUT), D13.1 (DIN)
unnamed: D13.3 (DOUT), D14.1 (DIN)
unnamed: D14.3 (DOUT), D15.1 (DIN)
unnamed: D15.3 (DOUT), D16.1 (DIN)
unnamed: D16.3 (DOUT), D17.1 (DIN)
unnamed: D17.3 (DOUT), D18.1 (DIN)
unnamed: D18.3 (DOUT), D19.1 (DIN)
unnamed: D19.3 (DOUT), D20.1 (DIN)
unnamed: D20.3 (DOUT), D21.1 (DIN)
unnamed: D21.3 (DOUT), D22.1 (DIN)
unnamed: D22.3 (DOUT), D23.1 (DIN)
unnamed: D23.3 (DOUT), D24.3 (DOUT)

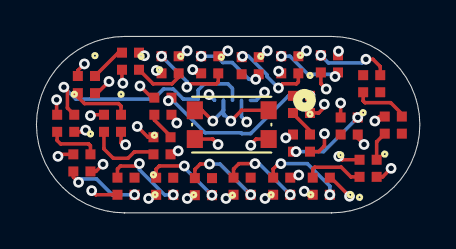
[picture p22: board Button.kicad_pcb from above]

Board: 4 copper layers, 21.3 x 9.8 mm, 26 parts (1 on the bottom side), 27 nets.

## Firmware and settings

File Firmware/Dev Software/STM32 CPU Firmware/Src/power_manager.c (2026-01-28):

/*
 * power_manager.c
 *
 *  Created on: Jan 24, 2026
 *      Author: Shariq
 */

#include "power_manager.h"

void Power_Init(I2C_HandleTypeDef *hi2c) {
    uint8_t config = 0xB0; // Enable ADC continuously
    HAL_I2C_Mem_Write(hi2c, BQ_I2C_ADDR, BQ_REG_ADC_CONTROL, 1, &config, 1, 100);
}

PowerStatus Power_GetStatus(I2C_HandleTypeDef *hi2c) {
    PowerStatus status;
    uint8_t raw_data[2];

    // Read Battery Voltage ADC
    if(HAL_I2C_Mem_Read(hi2c, BQ_I2C_ADDR, BQ_REG_BATSNS_ADC, 1, raw_data, 2, 100) == HAL_OK) {
        uint16_t raw_v = (raw_data[1] << 8) | raw_data[0];
        status.battery_voltage = raw_v * 0.001f; // Convert mV to V

        // Accurate lookup based on the BQ25622 internal scaling
        // In a real product, we would read the "Relative State of Charge" register if using a fuel gauge
        // For BQ25622, we use its high-res ADC to map percent
        status.charge_percent = (status.battery_voltage - 3.3f) / (4.2f - 3.3f) * 100.0f;
    }
    return status;
}

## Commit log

2026-01-05 Implement vehicle selection screen with custom vehicle addition
    - Added VehicleSelectionScreen for selecting and adding vehicles.
    - Integrated search functionality for vehicle models.
    - Implemented dialog for adding custom vehicles with type selection.
    - Enhanced vehicle selection logic with existing vehicle handling.
    - Added validation for device limits based on vehicle type.
    Introduce ANC audio output service
    - Created AncAudioOutput service for generating and playing anti-noise audio.
    - Implemented audio stream handling with inverted microphone input.
    - Added WAV header generation for audio playback.
    Develop ANC processor for adaptive noise control
    - Implemented AncProcessor to manage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
2026-01-13 Update dart.yml to include path filters
    Add path filters for push and pull_request events
2026-01-13 Switch Dart commands to Flutter in CI workflow
2026-01-19 Added support for battery
    [CB-42-2_ADI.step, CC-14-3_ADI.step, Serene Mini.kicad_pcb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]
2026-01-20 PCB and Schematic Design Changes
    Upgraded to the newer sr1120
    Reduced the PCB size by ~40%
    More efficient layout with chips on both side of the pcb
    [Serene Mini.kicad_pcb, Serene Mini.kicad_sch, freerouting.dsn]
2026-01-23 Final PCB and Schematic Design
    - Added new IC to support fast charging for batteries up to 3000mAh
    - Added a bluetooth chip
    - Used smaller coaxial ports to increase available space
    - The button is now located off the board connected via molax
    - Finished routing
    [2005280050.stp, 5034800500.STEP, BGM220S_SIL.step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]
2026-01-23 PCB Fixes
    Connected some missing traces and fixed some clearance issues
    [Serene Mini.kicad_pcb]
2026-01-23 Footprint Fixes
    Added/linked a 3D model to the molex connector.
    [Serene Mini.kicad_pcb]
2026-01-23 Changed Footprint
    Added cooling and repositioned the testpoint pads to be closer ti each other
    [Serene Mini.kicad_pcb]
2026-01-28 Minor Changes
    - Fixed minor issues in the PCB like routing the USB data lines parallel
    - Added BOM
    - Added blueprint folder containing everything required
    [2005280050.stp, 5034800500.STEP, BGM220S_SIL.step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]
2026-01-28 Added Documentation and Drill files
    [Serene Mini.kicad_pcb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]
2026-02-02 Minor Changes
    [Serene Mini.kicad_pcb, Serene Mini.kicad_sch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]
2026-02-05 Add initial README for Serene
    Added a detailed description of the Serene noise-cancelling device, including its inspiration, usage instructions, and sections for 3D model, PCB, wiring diagram, and BOM.
2026-02-05 Clean up README formatting
    Removed extra line breaks in PCB and Wiring Diagram sections.
2026-02-05 Add images for PCB and Casing in README
    Added images for PCB and Casing sections in README.
2026-02-05 Add detailed BOM to README
    Added a detailed Bill of Materials (BOM) with component specifications, quantities, prices, and sources.
2026-02-05 File Structure Changes
    [Serene Mini.csv]
2026-02-06 Enhance PCB selection explanation in README
    Expanded details on PCB selection and alternatives for DSPs.
2026-02-06 Revise PCB cost details and format screenshots section
    Updated PCB manufacturing details and changed heading format for screenshots.
2026-02-06 Update PCB manufacturing description in README
2026-02-06 Revise JLCPCB PCB descriptions in README
    Updated descriptions for JLCPCB PCB images to clarify manufacturing layers and costs.
2026-02-06 Changes to File Structure
    - Removed redundant blueprint folder
    - Made folder names more clear
    [2005280050.stp, 5034800500.STEP, BGM220S_SIL.step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]
2026-02-07 Added Stitching Vias
    [Serene Mini.kicad_pcb]
2026-02-07 Changes to PCB
    - Added 2 more filled zones, 1 on layer 3 and 4 respectively
    - Added stitching vias
    - Fixed some DRC Issues
    [Serene Mini.kicad_pcb]
2026-02-08 Fixed Issues with PCB
    [Serene Mini.kicad_pcb]
2026-02-08 Add new PCB image to README
2026-02-09 Update README with PCB and Wiring Diagram sections
    Added PCB and Wiring Diagram sections with images to README.
2026-02-09 Update README.md to remove duplicate image
    Removed duplicate image and adjusted layout for Button PCB section.
